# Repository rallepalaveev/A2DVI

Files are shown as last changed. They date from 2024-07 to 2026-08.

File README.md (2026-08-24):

# A2DVI - Apple II Digital Video

This is a project for a digital DVI/HDMI Apple II video card.
It directly produces a digital video stream from Apple II's memory content.
The signal is output via an HDMI connector, connecting the Apple II to modern displays with HDMI (or DVI) inputs.
No more analog signal conversion required.

The project is a collaboration with Thorsten Brehm. His related firmware project is here: https://github.com/ThorstenBr/A2DVI-Firmware

For the DVI output to be active, the new firmware developed by Thorsten should be used.

The card also has an alternative analog VGA connector.
For the VGA output to be active, the [VGA firmware](https://github.com/markadev/AppleII-VGA) developed by Mark Aikens should be used.

The card can produce either an analog VGA or a digital HDMI signal, but not both simultaneously.
To switch between modes, a firmware update is required and opening/closing connections.

As of v2.0 VGA function is not supported - the card is DVI only.

V2.2 has an onboard driver to invoke the configuation utility by PR#N, where N is the slot number.

V2.3 is a TH version with 74HC245 and requires a DVI break-out board.

V2.4 is a TH version with 74HC244 and requires a DVI break-out board.

## Procedure to activate DVI mode
* v1.2:
  program [A2DVI-Firmware](https://github.com/ThorstenBr/A2DVI-Firmware) to RPI Pico;
  remove U6 and disconnect pins 11, 12 and 13 of U5.
* v1.5:
  program [A2DVI-Firmware](https://github.com/ThorstenBr/A2DVI-Firmware) to RPI Pico;
  open all 9 DIP switches.
* v1.6:
  program [A2DVI-Firmware](https://github.com/ThorstenBr/A2DVI-Firmware) to RPI Pico;
  desloder the 8 soldering pads at GPIOs 14-21.
* v1.7:
  program [A2DVI-Firmware](https://github.com/ThorstenBr/A2DVI-Firmware) to RPI Pico;
  desloder the 8 soldering pads at GPIOs 14-21; remove VGA sub-board and ribbon cable.
* v2.0:
  program [A2DVI-Firmware](https://github.com/ThorstenBr/A2DVI-Firmware) to RPI Pico.
* v2.2:
  program [A2DVI-Firmware](https://github.com/ThorstenBr/A2DVI-Firmware) to RPI Pico.
* v2.3:
  program [A2DVI-Firmware](https://github.com/ThorstenBr/A2DVI-Firmware) to RPI Pico.
* v2.4:
  program [A2DVI-Firmware](https://github.com/ThorstenBr/A2DVI-Firmware) to RPI Pico.
  
## Procedure to activate VGA mode
* v1.2:
  program [VGA firmware](https://github.com/markadev/AppleII-VGA) to RPI Pico;
  replace U5 and U6.
* v1.5:
  program [VGA firmware](https://github.com/markadev/AppleII-VGA) to RPI Pico;
  close all 9 DIP switches.
* v1.6:
  program [VGA firmware](https://github.com/markadev/AppleII-VGA) to RPI Pico;
  sloder the 8 soldering pads at GPIOs 14-21.
* v1.7:
  program [VGA firmware](https://github.com/markadev/AppleII-VGA) to RPI Pico;
  sloder the 8 soldering pads at GPIOs 14-21; connect VGA sub-board to main board by the ribbon cable.
* v2.0:
  N.A. - v2.0 is HDMI only.
* v2.2:
  N.A. - v2.2 is HDMI only.
* v2.3:
  N.A. - v2.3 is HDMI only.
* v2.4:
  N.A. - v2.4 is HDMI only.
* v4.4:
  N.A. - v4.4 is HDMI only.
* v4.6:
  N.A. - v4.6 is HDMI only.
  * v5.x:
  N.A. - v5.x are HDMI only.

Note: In version 2.4 I experimented with replacing the 8x 270-ohms resistors on the DVI lines by 100pF capacitors to achieve better separation form potential 3.3V DC leak from the screen; while this worked, some screens are more prone to noise and results may still be better with the 270-ohms resistors.

Note2: Version 4.4 is bidirectional and can work as a variety of functionalities. Firmware is closed source so far. V4.6 has some optimizations.

Note3: Versions 5.x are based on CPB with RP2354B and are 5V tolerant and has 48 GPIOs available. This eliminates the need
for level shifting and multiplexing. This version had DVI function and can support RTC via a dedicated connector.

## Dual-Language Support
The pin on the v1.5 and later boards is for AltChr connection, supported by A2DVI firmware for switching between alternative character sets on non-US versions of Apple II ("Euro-machines").

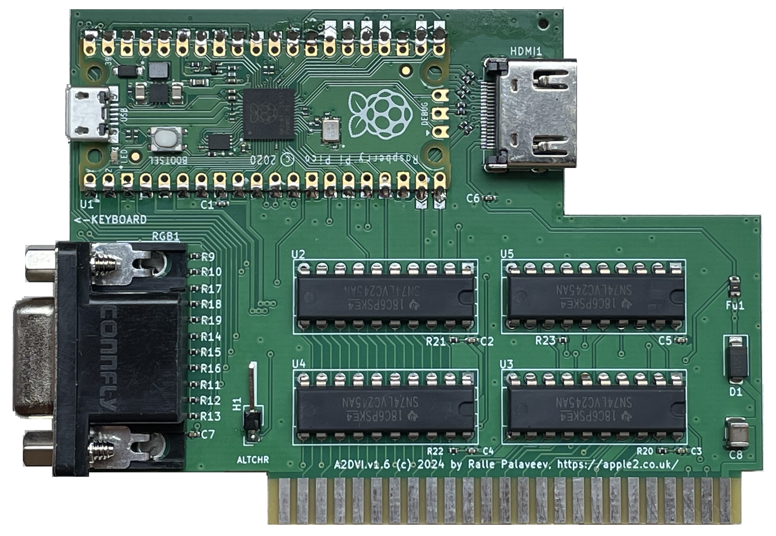
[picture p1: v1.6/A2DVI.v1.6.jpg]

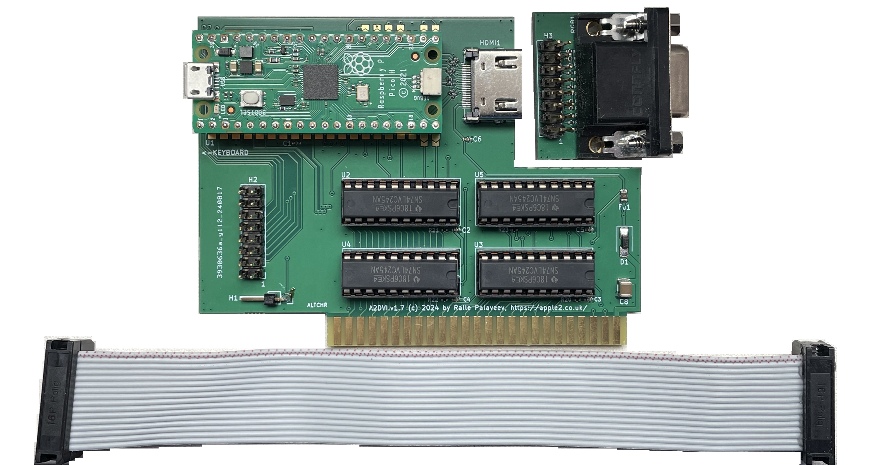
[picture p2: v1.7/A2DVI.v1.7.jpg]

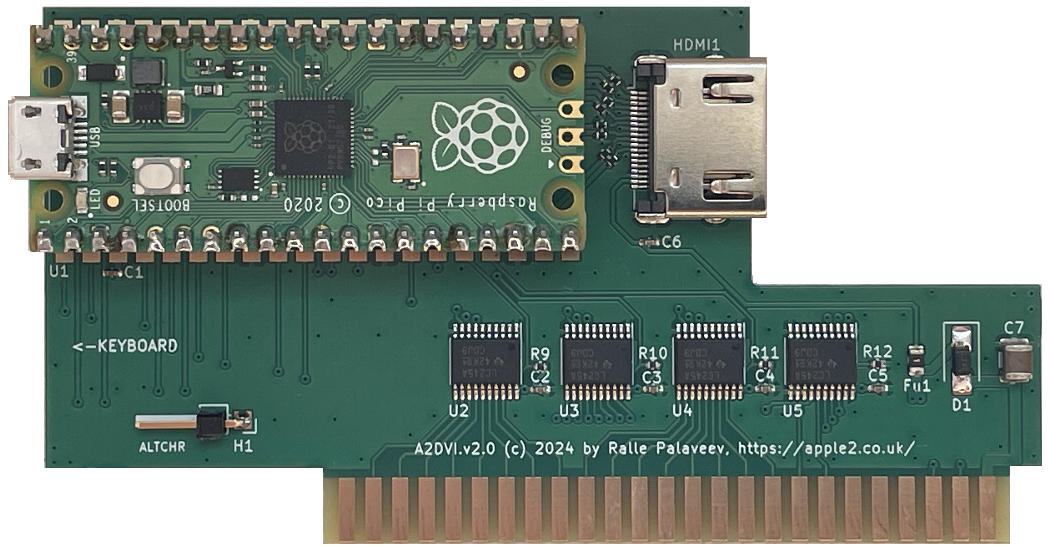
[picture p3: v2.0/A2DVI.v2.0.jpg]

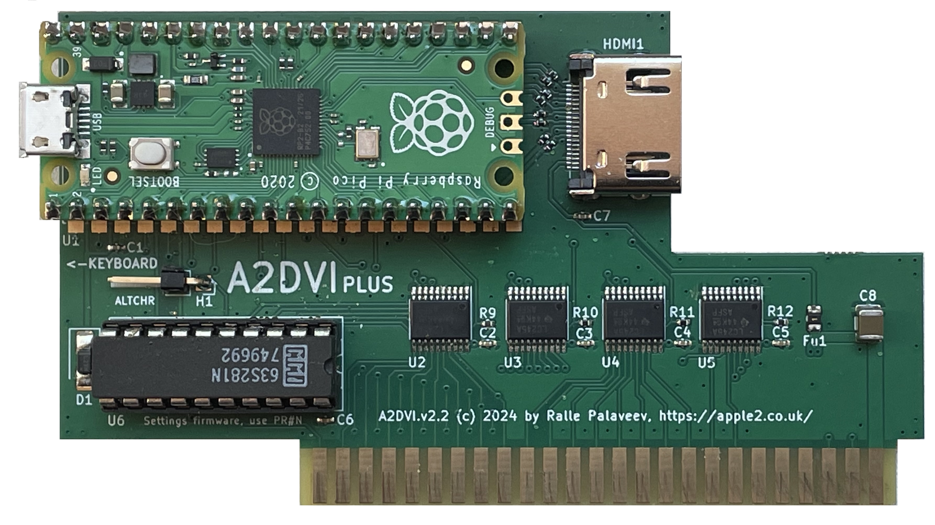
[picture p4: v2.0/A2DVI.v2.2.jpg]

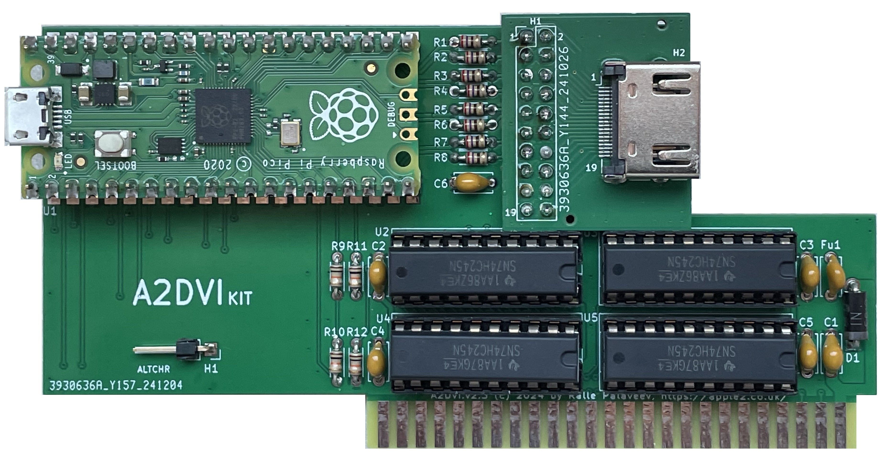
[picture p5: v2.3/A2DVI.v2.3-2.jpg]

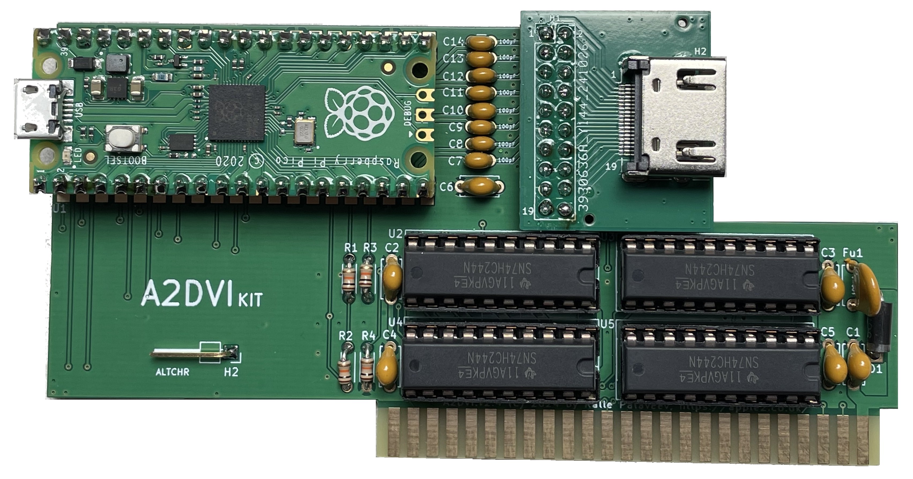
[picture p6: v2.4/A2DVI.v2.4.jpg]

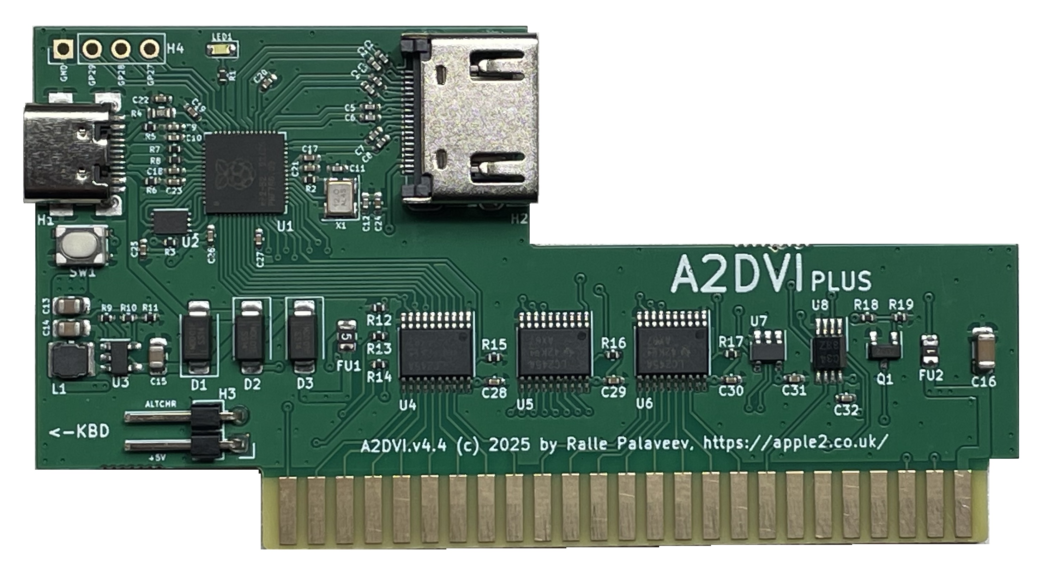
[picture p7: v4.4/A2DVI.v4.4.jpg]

A2DVI PCB
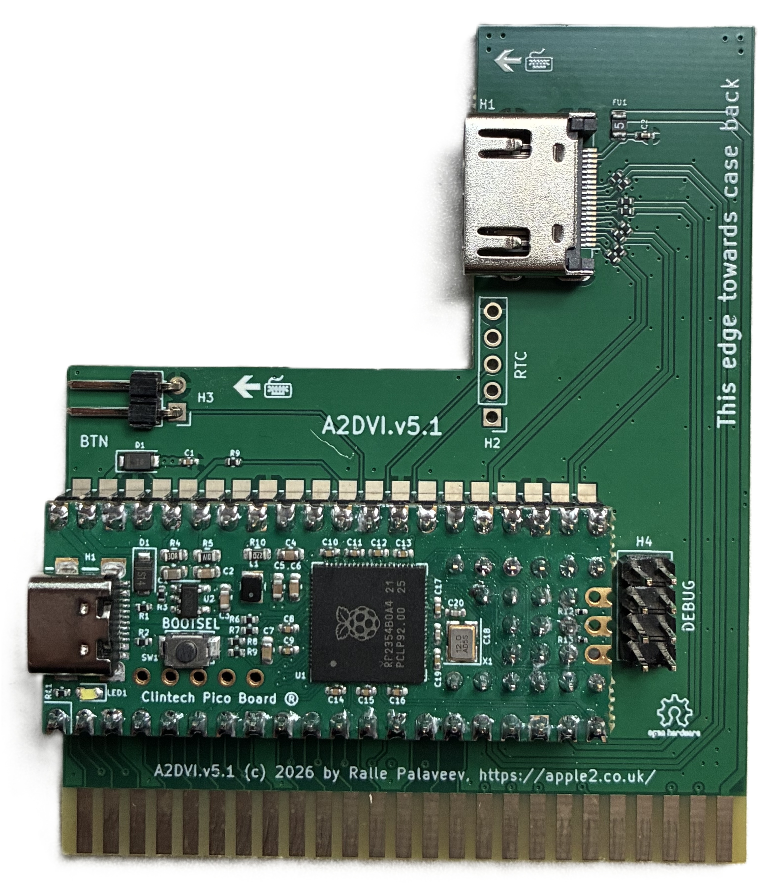
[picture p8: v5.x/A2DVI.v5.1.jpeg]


# Hardware
* Based on the PICO controller board.
* Provides a DVI video stream via an HDMI connector.
* Low power/heat dissipation: less than 70mA@5V = 0.35W in operation.
* Uses 4x 74LV245 bus transceivers for 5V/3.3V signal conversion of the Apple II bus.
* Separate ALTCHR input pin for dual-language support: pin needs to be wired separately to the "language switch" of Euro-Apple IIs (optional).
* Versions 5.x do not need level shifters.

# Thanks
This is a project based on:

* the AppleII-VGA project by Mark Aikens - https://github.com/markadev/AppleII-VGA

* the PicoDVI project by Luke Wren - https://github.com/Wren6991/PicoDVI

* Thorsten Brehm for firmware development and board design considerations

* Oliver Schmidt on original idea discussions and design considerations

* Mike Neil for adapting the firmware for v5.x.

# License
Board design by Ralle Palaveev (c) 2026.

All rights reserved.

Redistribution and use in source, binary, and manufactured forms, with or without
modification, are permitted provided that the following conditions are met:
1. Redistributions of source code and design files must retain the above copyright
   notice, this list of conditions and the following disclaimer.
2. Redistributions in binary or manufactured form must reproduce the above copyright
   notice, this list of conditions and the following disclaimer in the
   documentation and/or other materials provided with the distribution.
3. All advertising materials mentioning features or use of this software
   or hardware must display the following acknowledgement:
   This product includes software or hardware developed by Ralle Palaveev.
4. Neither the name of Ralle Palaveev nor the
   names of its contributors may be used to endorse or promote products
   derived from this software or hardware without specific prior written permission.

The above copyright notice and this permission notice shall be included in all
copies or substantial portions of the Software.

THE SOFTWARE IS PROVIDED "AS IS", WITHOUT WARRANTY OF ANY KIND, EXPRESS OR
IMPLIED, INCLUDING BUT NOT LIMITED TO THE WARRANTIES OF MERCHANTABILITY,
FITNESS FOR A PARTICULAR PURPOSE AND NONINFRINGEMENT. IN NO EVENT SHALL THE
AUTHORS OR COPYRIGHT HOLDERS BE LIABLE FOR ANY CLAIM, DAMAGES OR OTHER
LIABILITY, WHETHER IN AN ACTION OF CONTRACT, TORT OR OTHERWISE, ARISING FROM,
OUT OF OR IN CONNECTION WITH THE SOFTWARE OR THE USE OR OTHER DEALINGS IN THE
SOFTWARE.

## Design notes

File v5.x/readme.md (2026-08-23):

This is based on Clintech Pico Board (CPB) with 48 GPIOs, most 5V tolerant.

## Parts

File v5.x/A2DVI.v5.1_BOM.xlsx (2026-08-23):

Comment | Designator | Footprint | JLCPCB Part #（optional）
16V 100nF X7R ±10% 0402 Multilayer Ceramic Capacitors MLCC - SMD/SMT ROHS | C1,C2 | 0402 | C1525
DSS14 | D1 | SOD-123FL | C2923923
6V 500mA Resettable Fuse | FU1 | 0805-50 | C269104
HDMI connector | H1 |  | C2906135
270 | R1,R2,R3,R4,R5,R6,R7,R8 | 0402 | C324790
1k | R9 | 0402 | C11702

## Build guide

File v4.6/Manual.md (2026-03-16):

# A2DVI.v4.6: Digital Video card for Apple II Computers with multifunction capabilities

## Preface

This is a firmware project for a digital DVI/HDMI video card for Apple II. It directly produces a digital video stream from the Apple II's memory content. The signal is output via an HDMI connector, connecting the Apple II to modern displays with HDMI (or DVI) inputs. No analog signal conversion is required.

The project is a collaboration between Ralle Palaveev and Thorsten Brehm. 

The hardware is based on the PICO controller board. Both, original PICO (RP2040) and PICO2 (RP2350) modules are supported. Separate firmware is provided for the two PICO variants.

The initial designs v1.x and v2.x have been unidirectional where the card is snooping on the A2 computer address, data and control buses and creates a shadow image of what is to be displayed. The image is then sent to the HDMI output as digital video. More information on the technology is here: https://github.com/ThorstenBr/A2DVI-Firmware

Version 4.x of the card is now bi-directional and the hardware is directly manufactured with a RP2040 processor on board, instead a RPI Pico.

This new design allows for housing of programs on the card which can communicate back and forth with the A2 computer. This has allowed for several firmwares to be pre-loaded on the card and each one can be used at a time, turning the card into a specific function card.

## Firmwares on the card

Currently there are 5 firmwares on the card:

1. A2DVI - HDMI video display adapter
2. Z80 emulator for Applicard CPM
3. Apple II Mouse (PAL) - an adapter for a USB mouse for Apple2 for PAL video timing
4. Apple II Mouse (NTSC) - an adapter for a USB mouse for Apple2 for NTSC video timing
5. USB Floppy Disk II

Only one firmware is active at a time. A firmware can be selected by an initial selection menu, which can be invoked within 15 seconds of powering the computer by calling PR#N command, where N is the slot number.

Once the computer is powered, DVI is always active during the 15s timeout, so that the user can see the menu for firmware selection. If the DVI firmware is not the one selected, the bottom of the screen displays which firmware would become active and the timeout counter. During the initial 15s timeout the LED blinks very fast.

Once a firmware is selected, the timeout ends immediately and the selected firmware becomes active.

Alternatively, if during the 15 second timeout nothing is done, upon timeout completion the previously selected firmware becomes active.

If cold reset is performed (Ctrl-OpenApple-Reset), this does not affect the function of the firmware - the timeout is not invoked. It is only active after a power on.

## Each firmware function is described below.

1. A2DVI. All functions are the same as described in the original design of version 2.x: https://github.com/ThorstenBr/A2DVI-Firmware The only difference is that by running PR#N, while DVI is active, the DVI configuration menu would be started - no config disk is needed. During DVI function the LED blinks fast.

2. Z80 emulator for Applicard CPM. If this mode is selected, then the user can boot Applicard CPM, an example disk is here: https://github.com/rallepalaveev/A2DVI/blob/main/v4.4/PCPI%20AppliCard%20D1.po Suggested card slot: 4.

3. Apple II Mouse Card (PAL). This firmware turns the card into a Mouse controller - it has to be installed in Slot4 and a USB mouse connected to the USB-c port of the card (an adapter may be needed for USB-A mouse). Once the firmware becomes active (15s after power-on), the card can be used by programs like A2Desktop.

4. Apple II Mouse Card (NTSC). This firmware turns the card into a Mouse controller - it has to be installed in Slot4 and a USB mouse connected to the USB-c port of the card (an adapter may be needed for USB-A mouse). Once the firmware becomes active (15s after power-on), the card can be used by programs like A2Desktop.

5. When FDD is selected and activated, the LED blinks slowly until the 2 floppy disk images are selected; calling PR#N displays a menu to select disk images for the 2 floppy disk drives. The 140kB .dsk images must be on a thumb drive connected to the USB-c port of the card. After selecting the disk images, the LED blinks synchronously with the floppy disk access. Currently works on IIe only. If programs require to change disks: The current solution is to connect an external button (A2DVIplus has a two pin connector to connect a button/switch). The firmware detects floppy images with names only differing in a single digit. So, the trick is to prepare the disk images to follow a naming scheme. "Oregon Trail - Disk1.dsk", "Oregon Trail - Disk 2.dsk" etc. Then you just select the boot disk via the menu. And when the program later asks to flip/cycle disks, you simply press the button to advance one digit ahead. The firmware automatically cycles through the disk images - in ascending order. Just sometimes requires a bit of preparation. Something like "Prince of Persia (boot disk).dsk", "Prince of Persia (side a).dsk" doesn't work, so some images need to be renamed.

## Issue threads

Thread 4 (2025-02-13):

No A2DVI Card in Slot X #20

amazingcobrazil, 2025-02-13:
Hello,
I assembled a board for my own use, and it is displaying the image normally, but when I run the configuration utility files, it displays the error message:
No A2DVI Card in Slot 1
I have already tried changing it to other slots on my Apple IIe and the message is the same. I tried both the A2DVICONFIG_DOS33.dsk and A2DVICONFIG_DOS33.po images (downloaded from the same package as the latest firmware 1.7)
My board version: 2.0
What could it be?

rallepalaveev, 2025-02-13:
Hi,

Where is this message displaying? On the standard Apple2 output or on the HDMI? Please note that while the CONFIG is running, the outputs are showing different screens.

Let me know if that helps.

Closed 2025-03-11.

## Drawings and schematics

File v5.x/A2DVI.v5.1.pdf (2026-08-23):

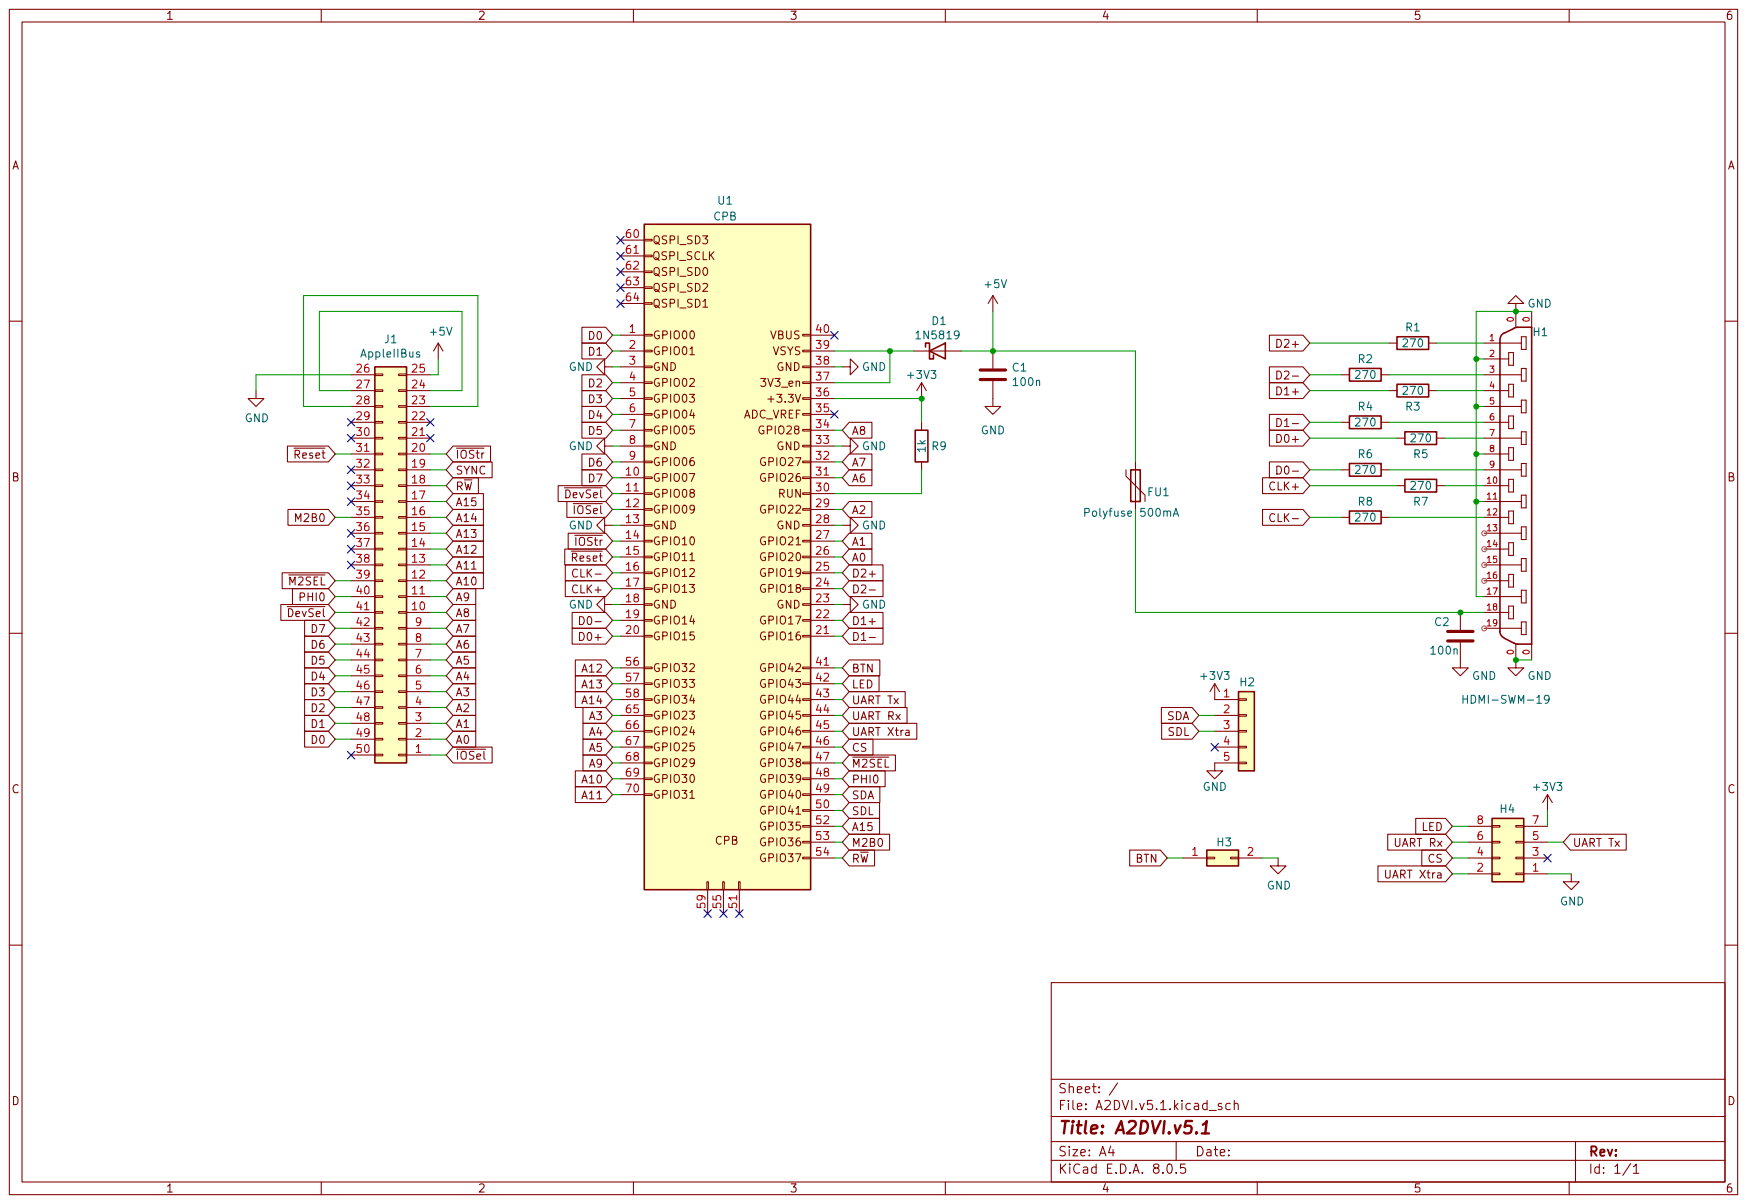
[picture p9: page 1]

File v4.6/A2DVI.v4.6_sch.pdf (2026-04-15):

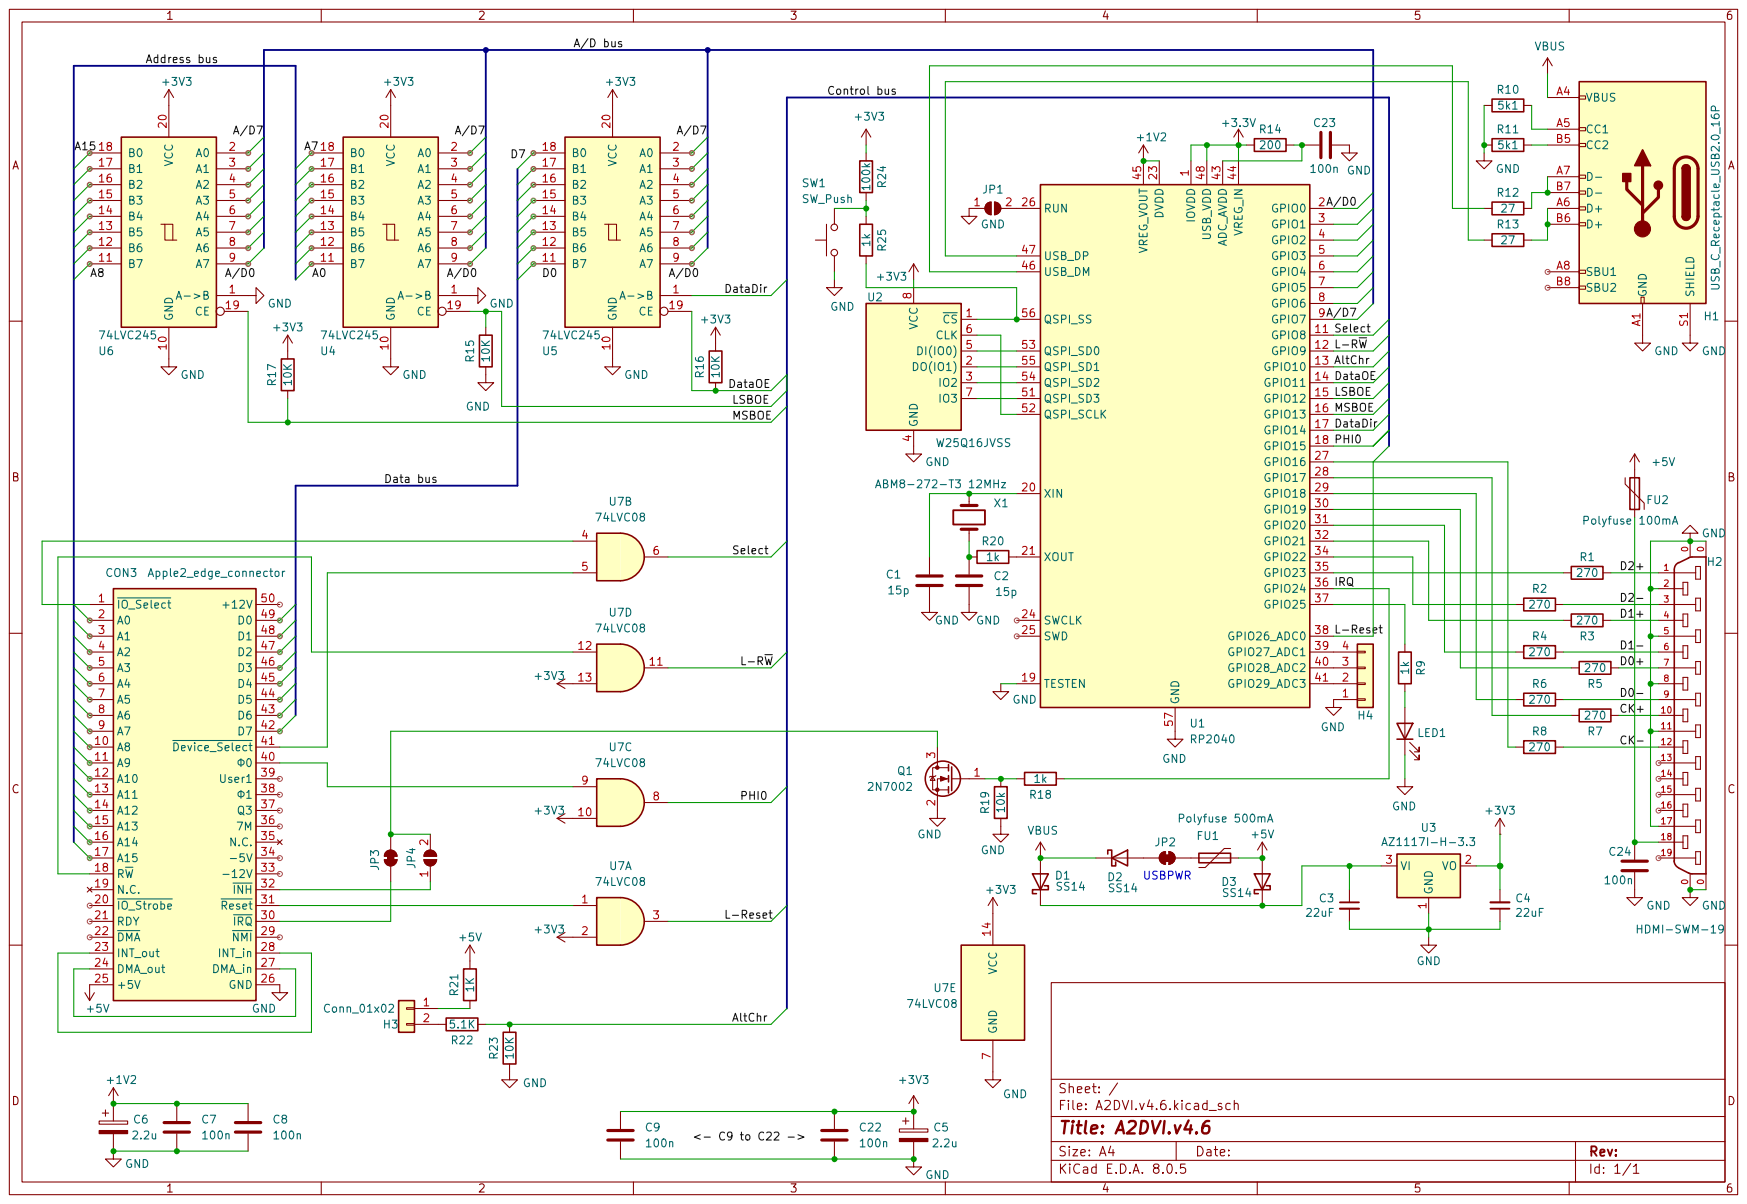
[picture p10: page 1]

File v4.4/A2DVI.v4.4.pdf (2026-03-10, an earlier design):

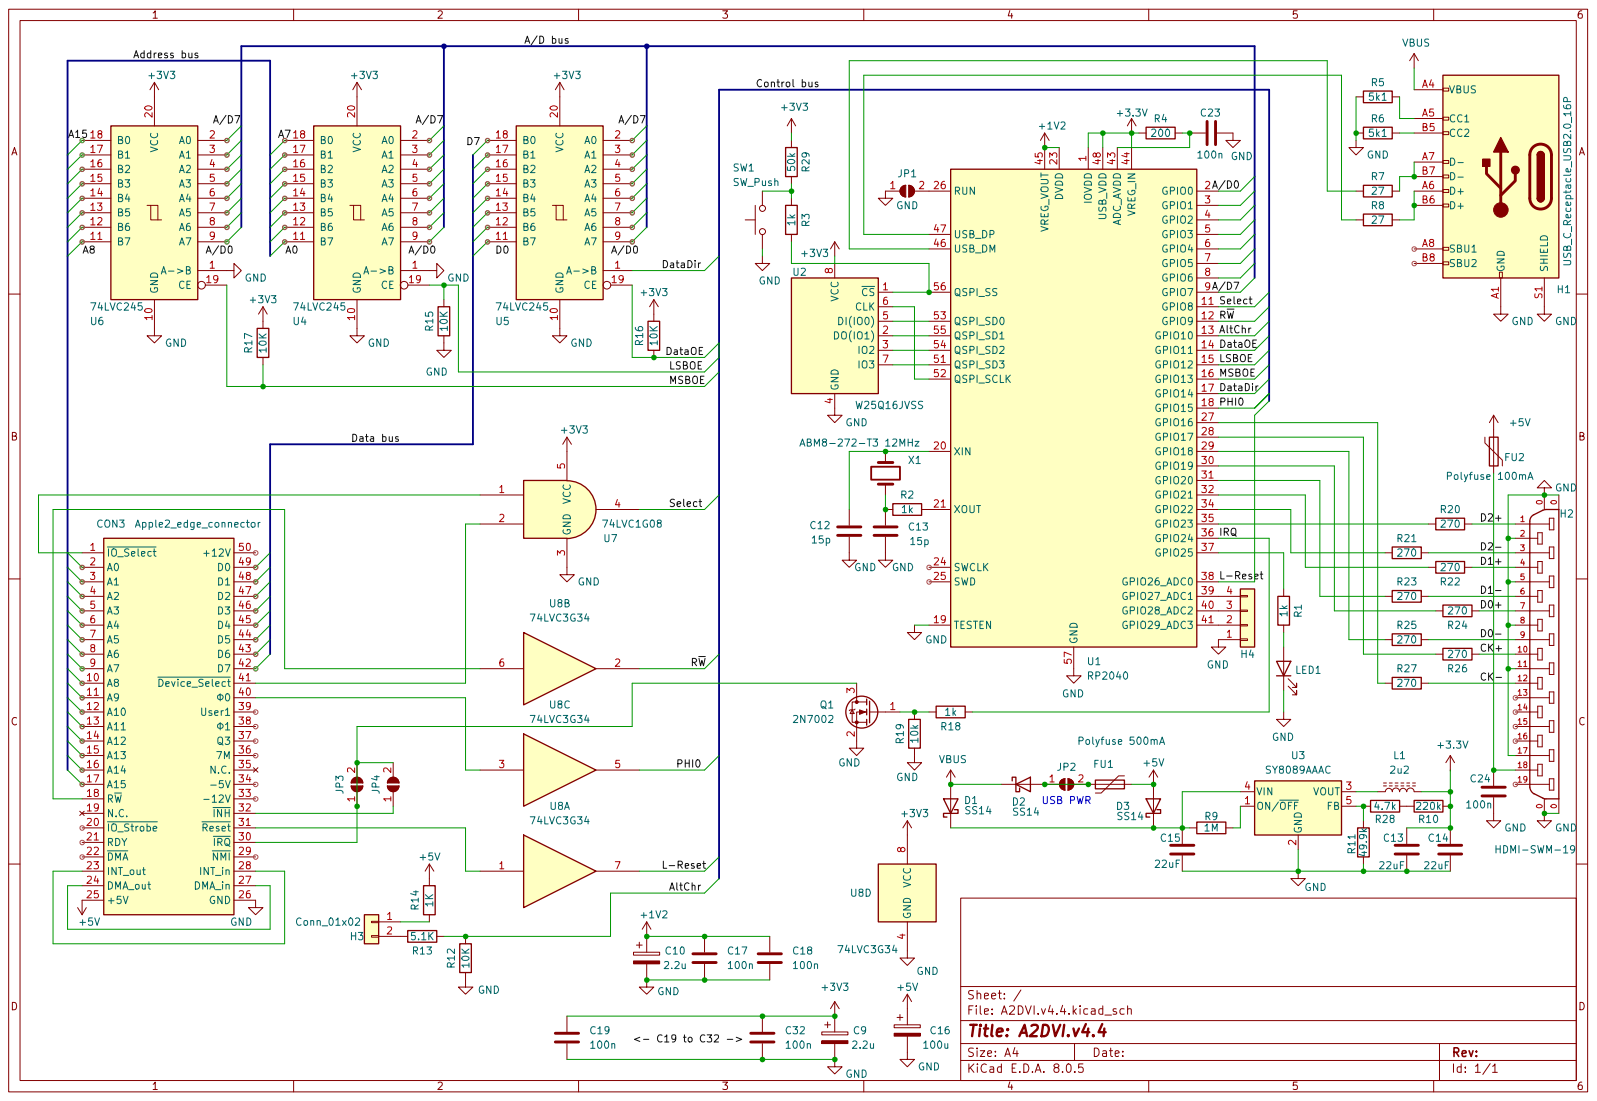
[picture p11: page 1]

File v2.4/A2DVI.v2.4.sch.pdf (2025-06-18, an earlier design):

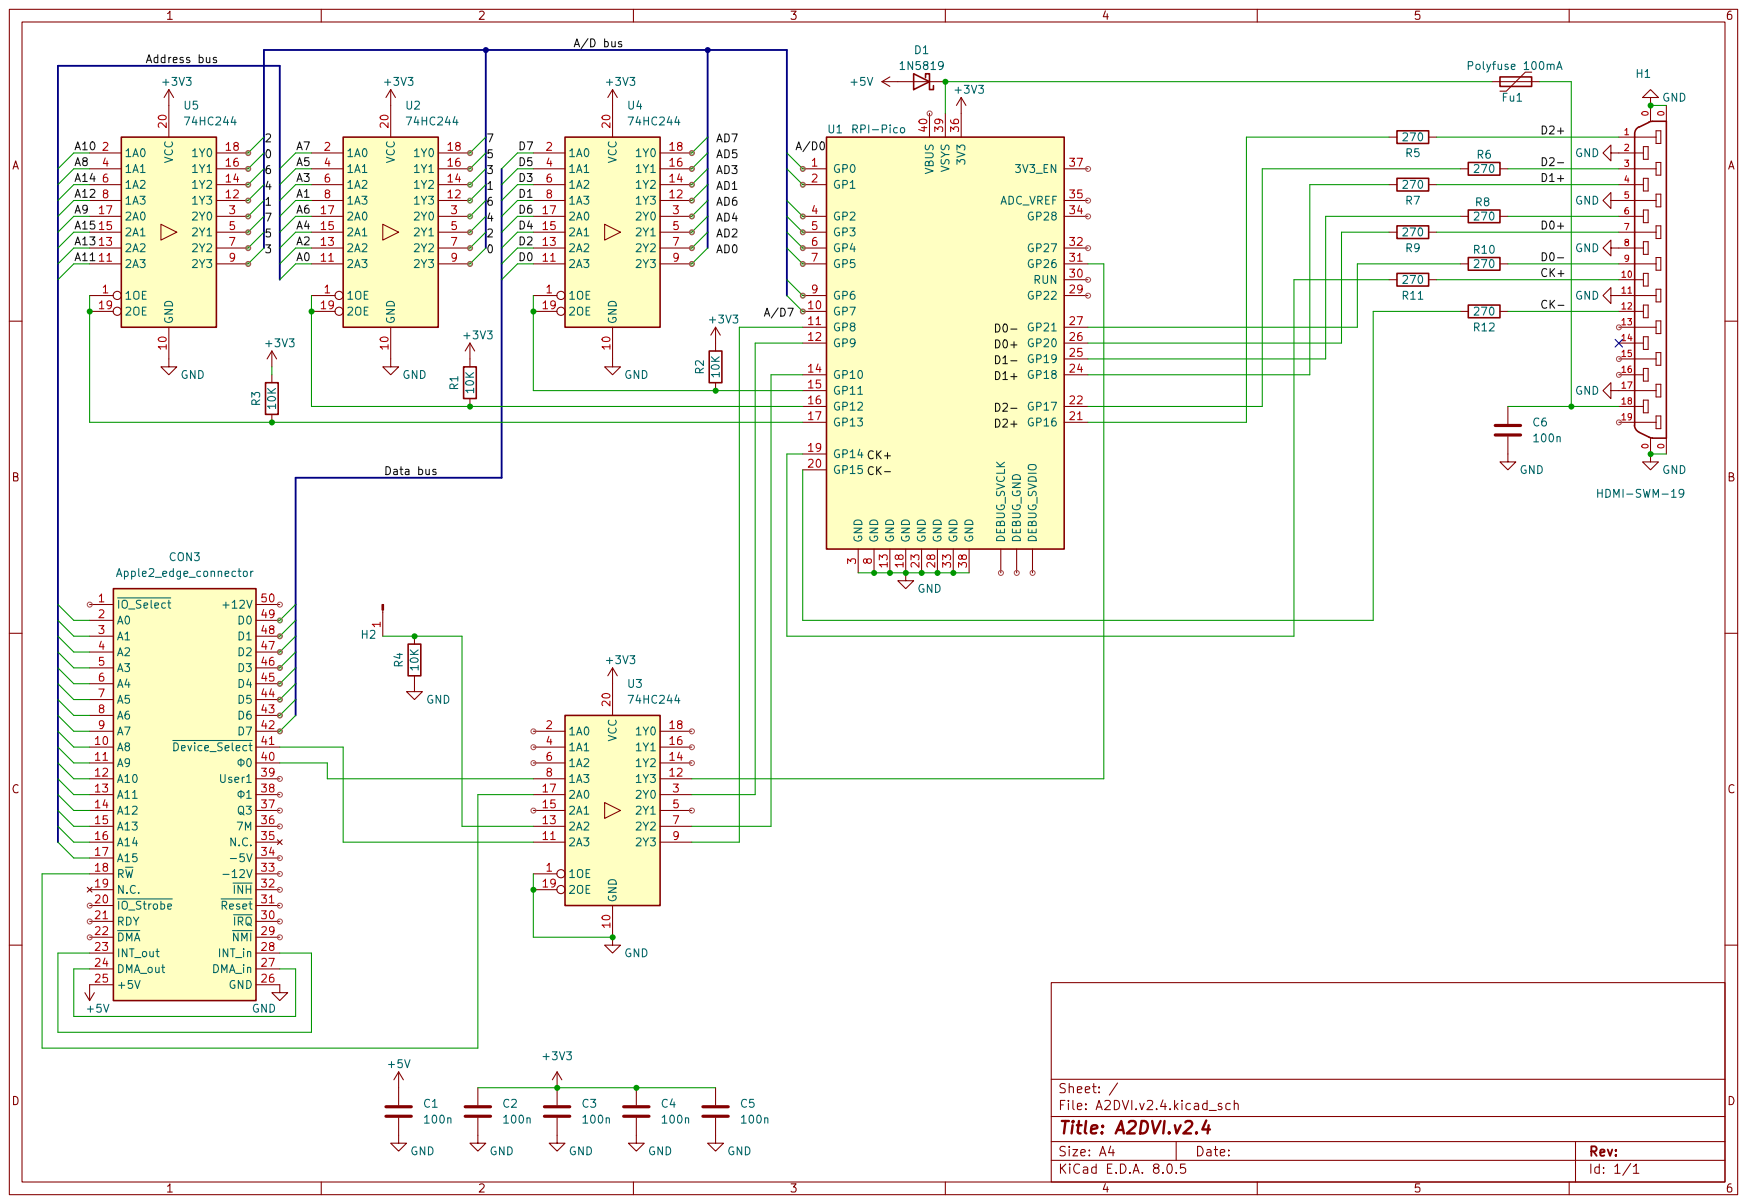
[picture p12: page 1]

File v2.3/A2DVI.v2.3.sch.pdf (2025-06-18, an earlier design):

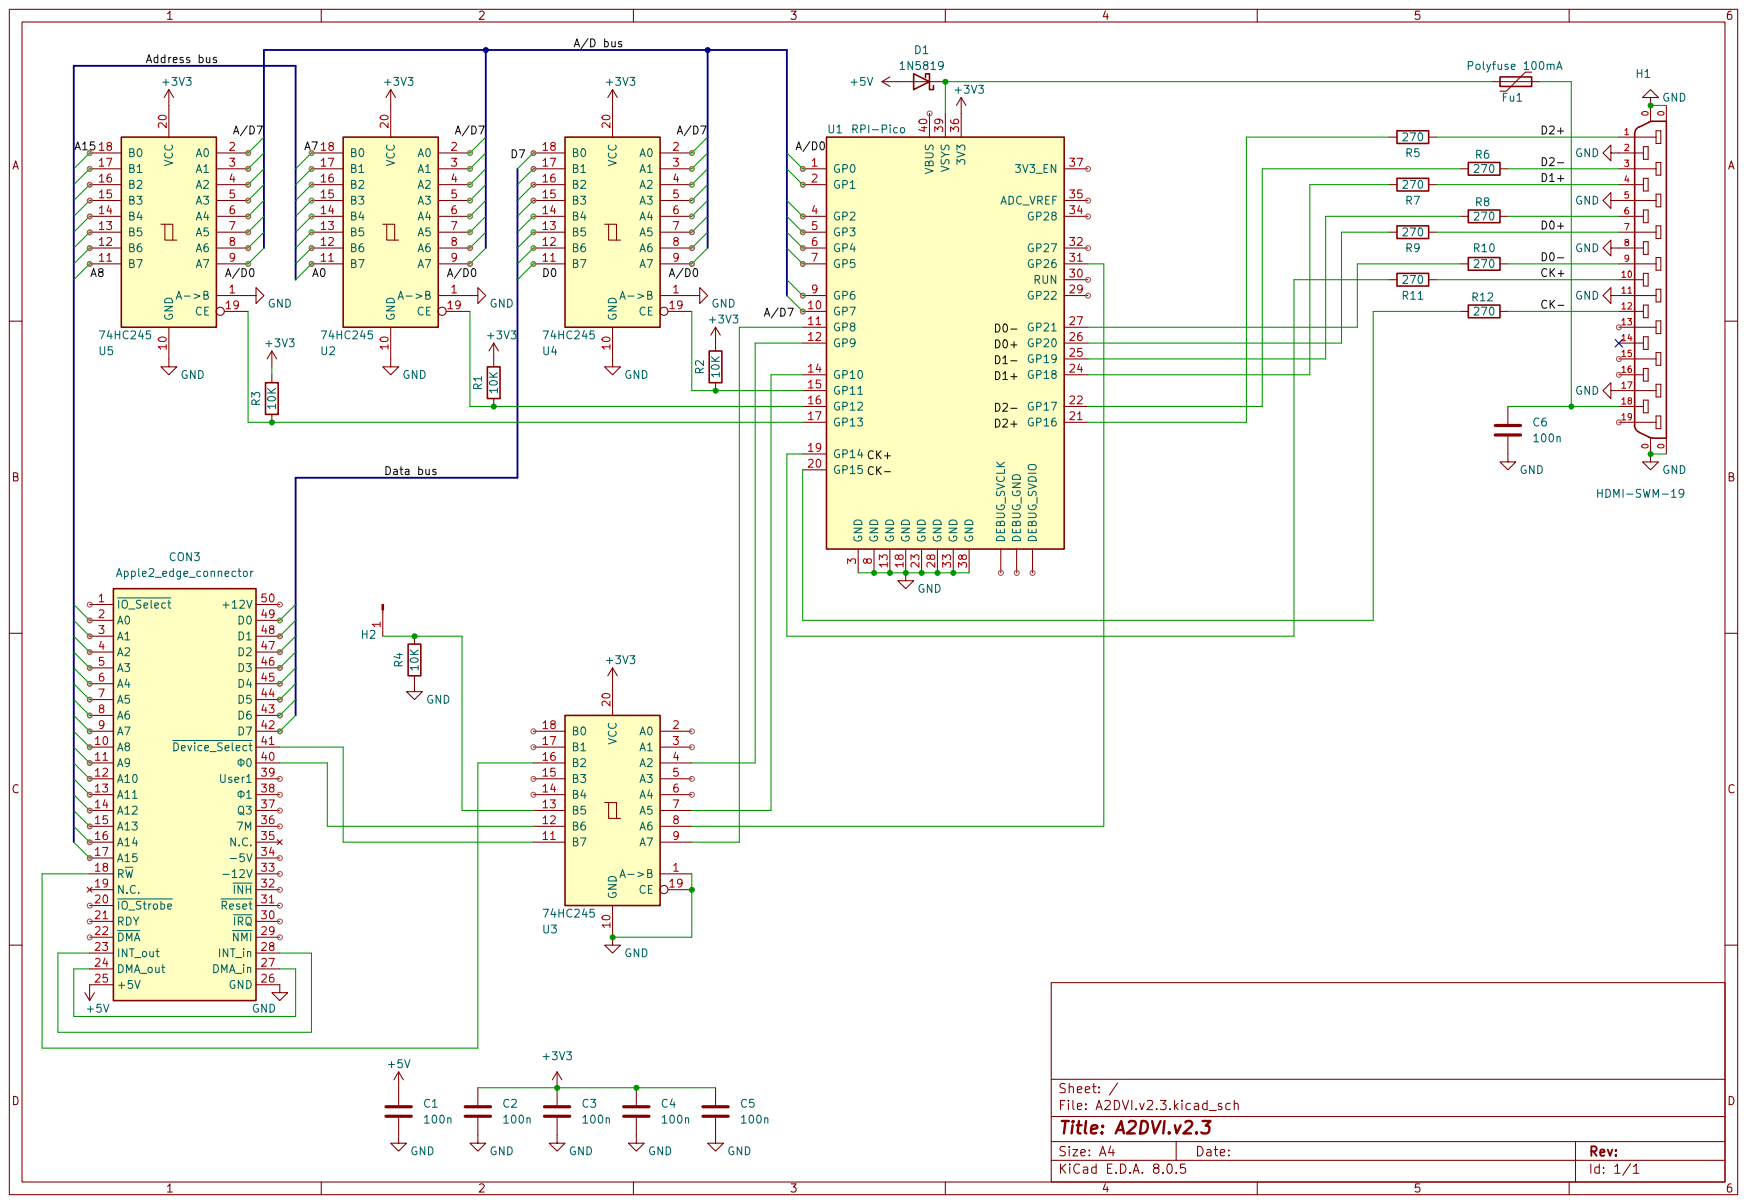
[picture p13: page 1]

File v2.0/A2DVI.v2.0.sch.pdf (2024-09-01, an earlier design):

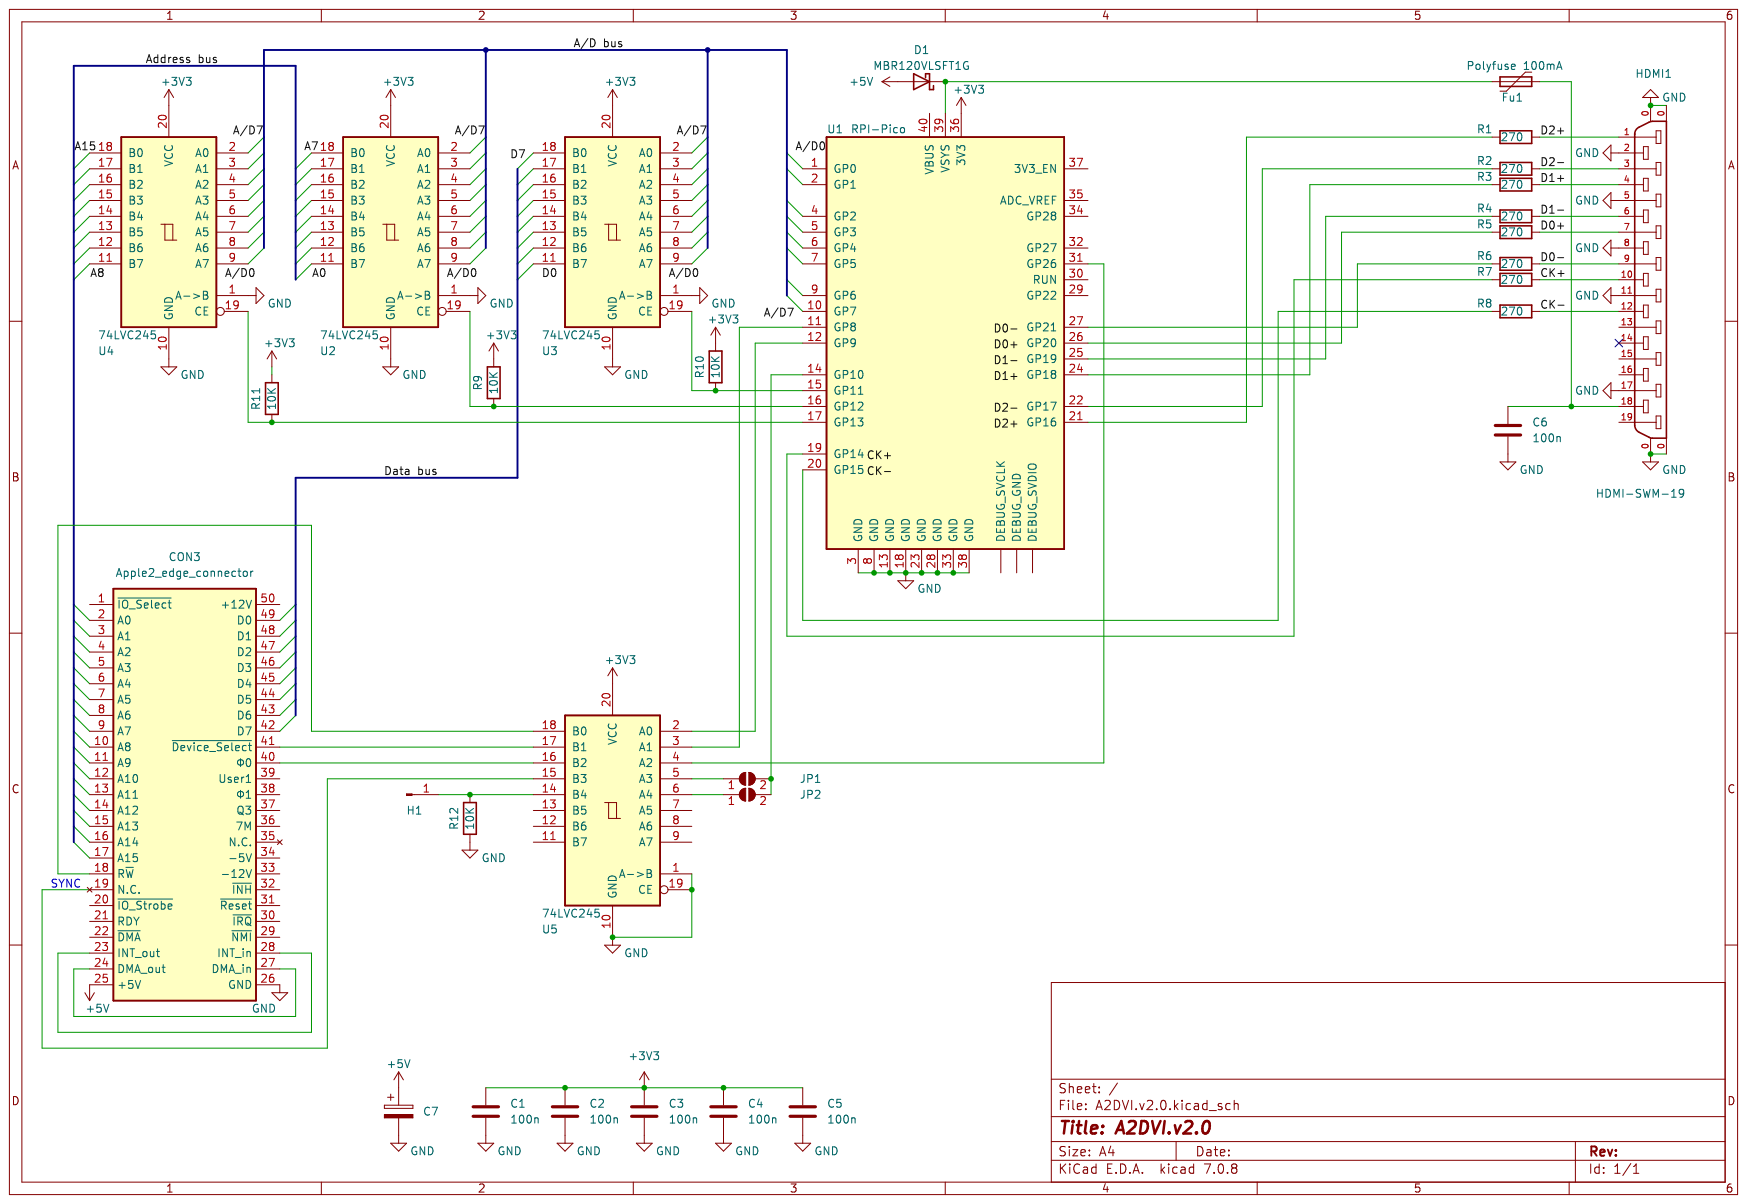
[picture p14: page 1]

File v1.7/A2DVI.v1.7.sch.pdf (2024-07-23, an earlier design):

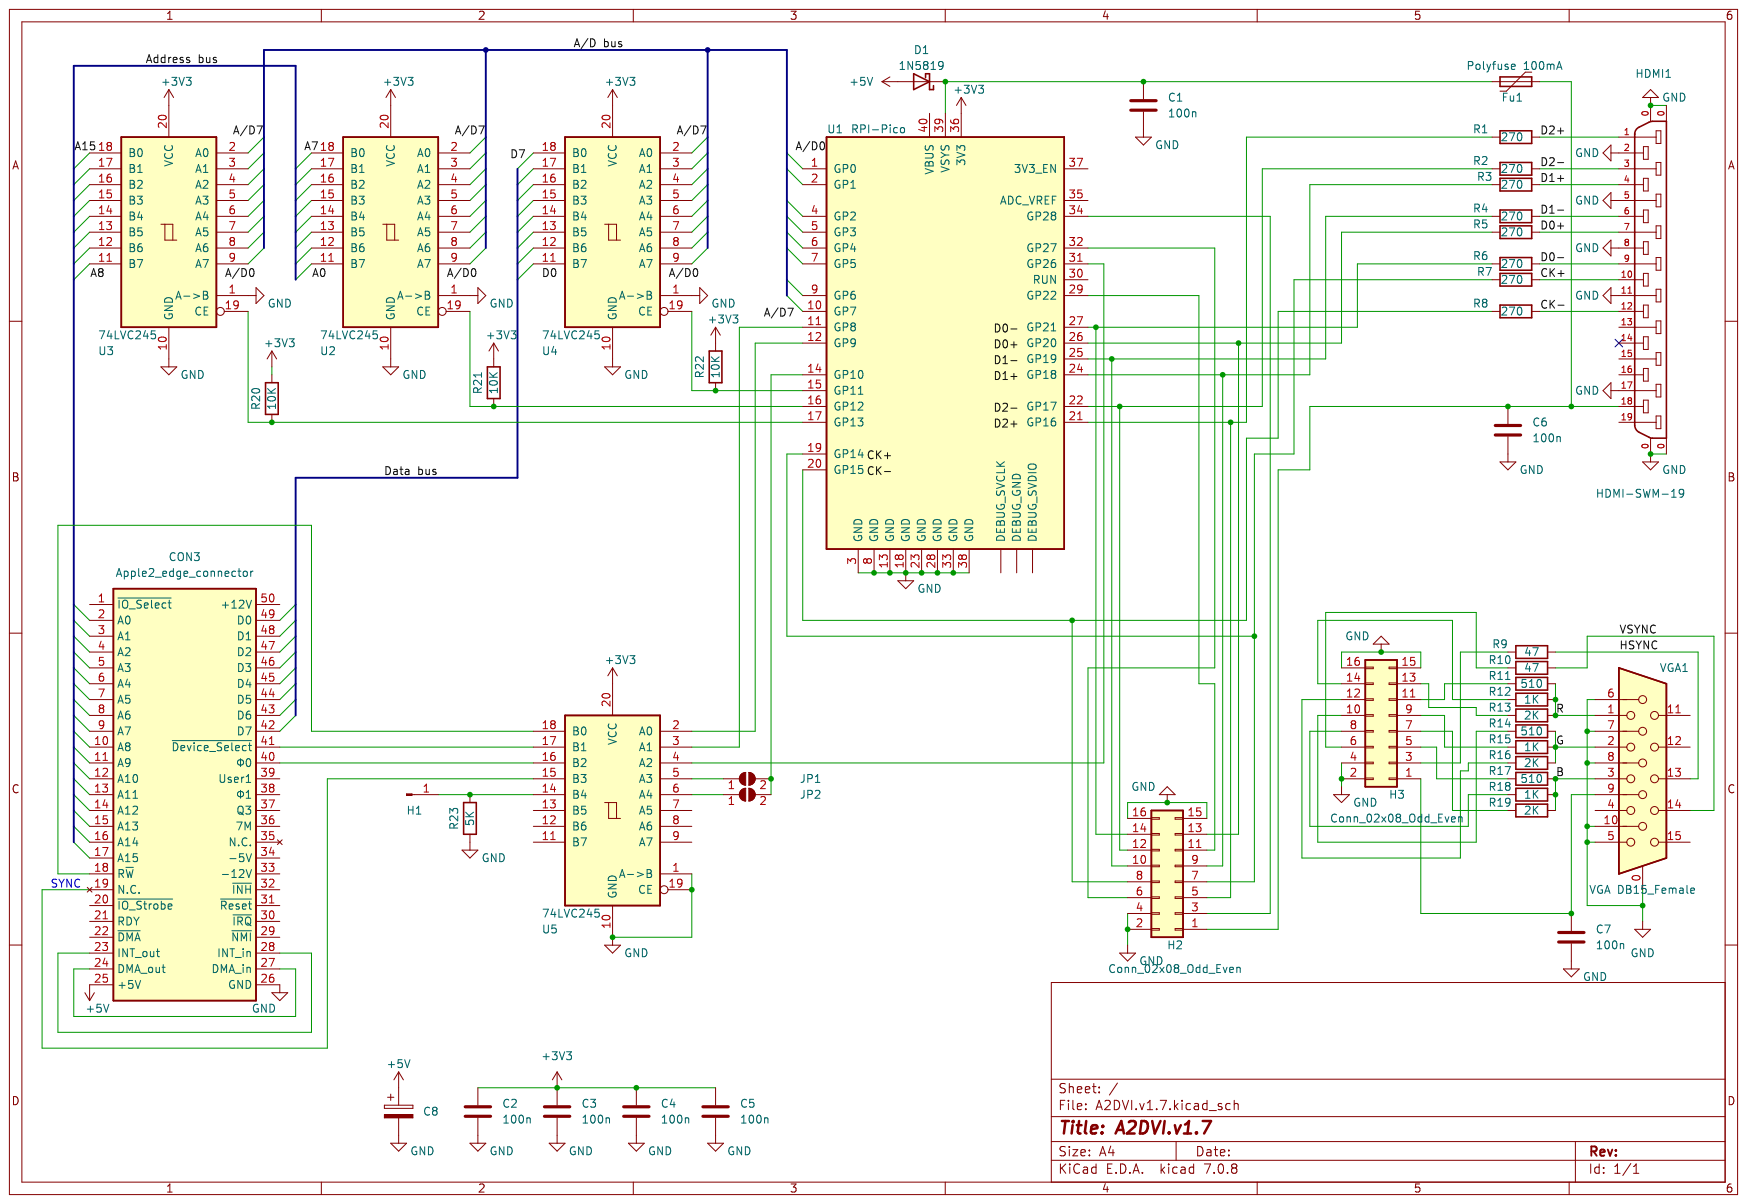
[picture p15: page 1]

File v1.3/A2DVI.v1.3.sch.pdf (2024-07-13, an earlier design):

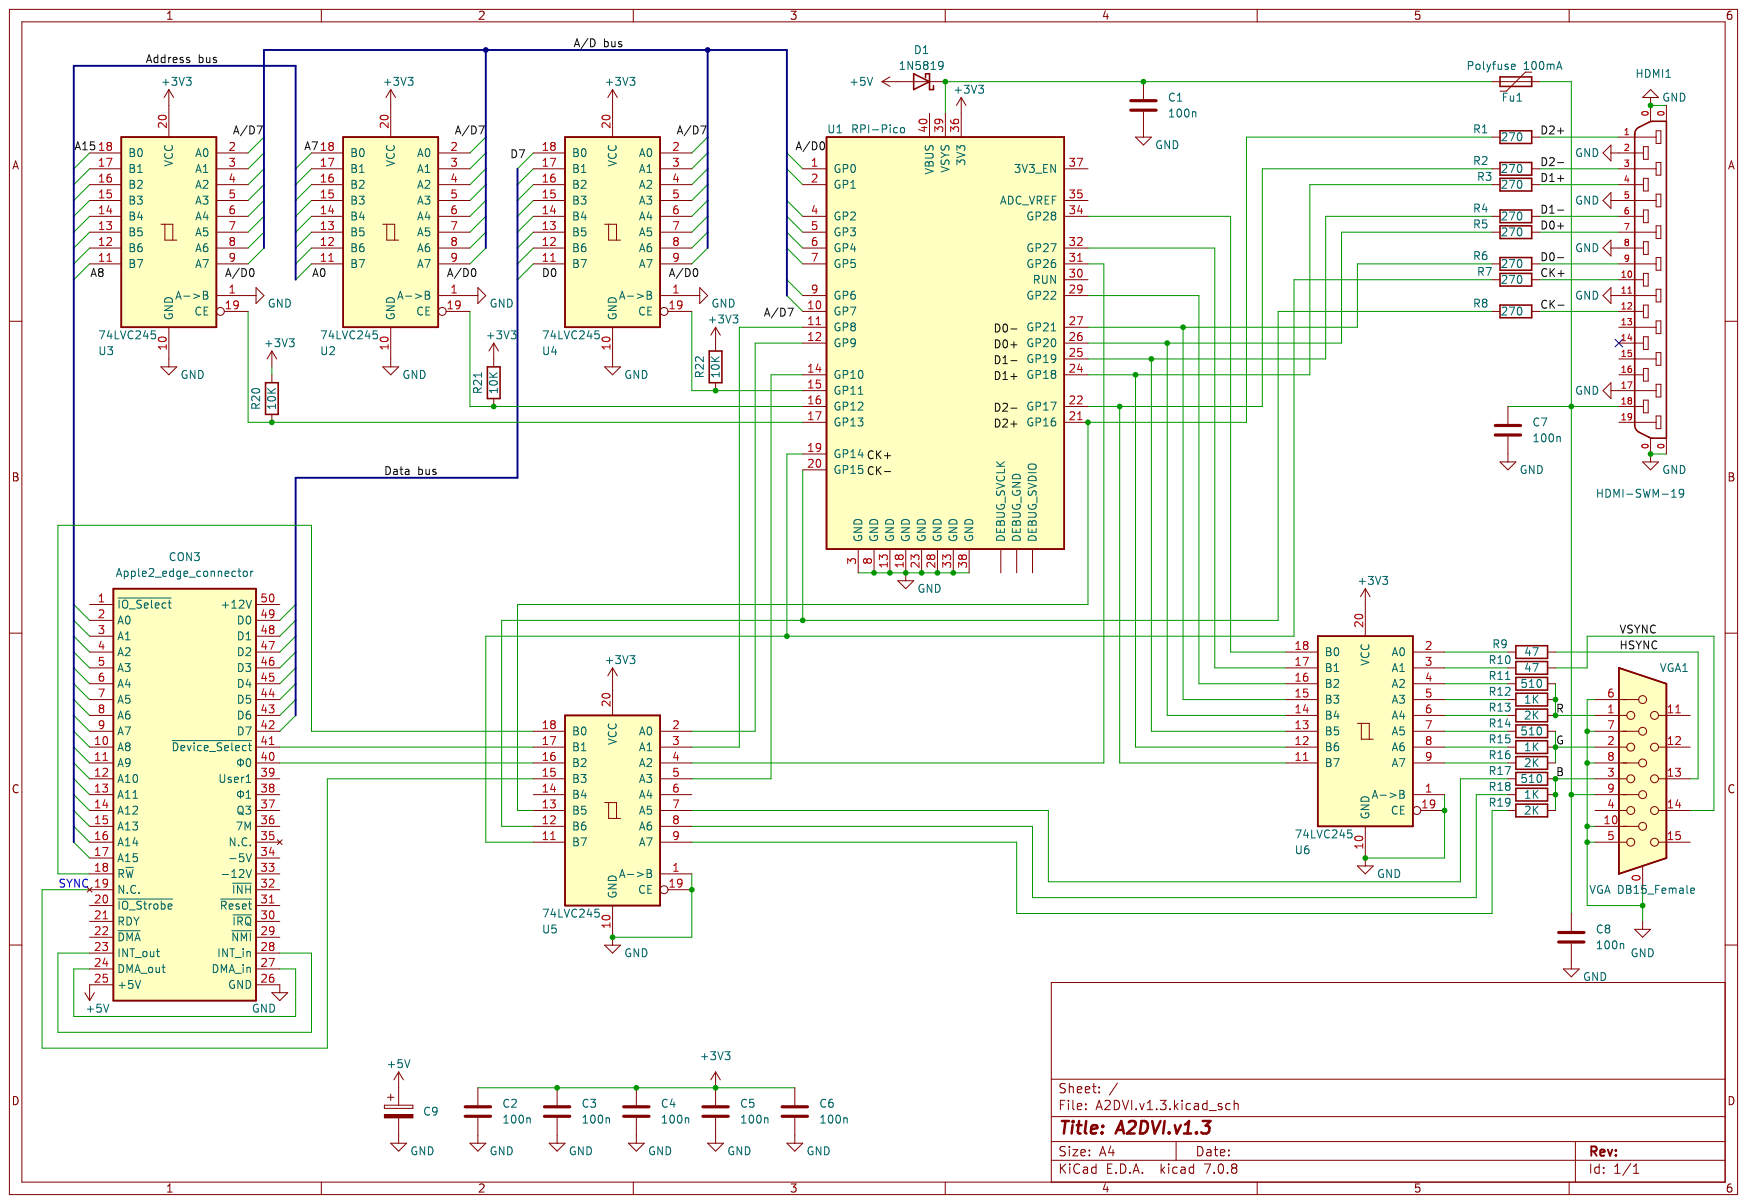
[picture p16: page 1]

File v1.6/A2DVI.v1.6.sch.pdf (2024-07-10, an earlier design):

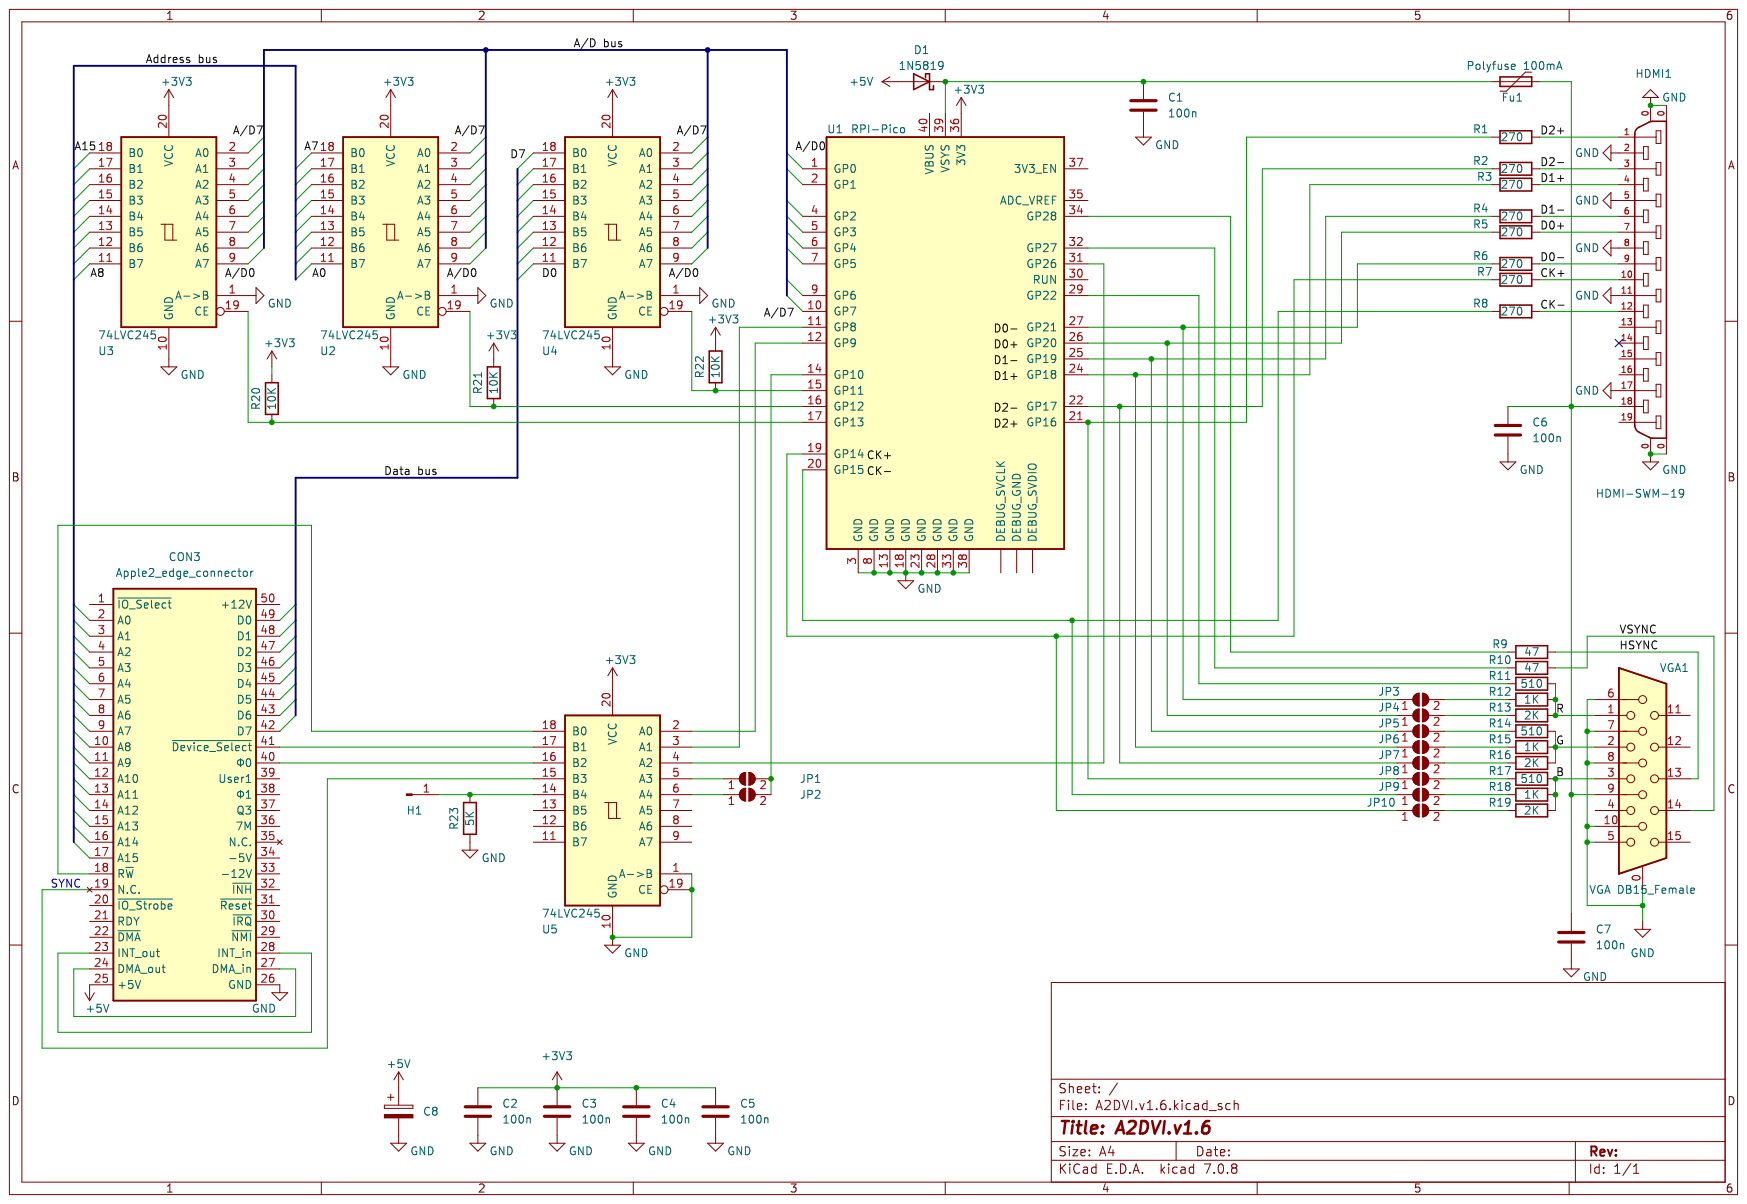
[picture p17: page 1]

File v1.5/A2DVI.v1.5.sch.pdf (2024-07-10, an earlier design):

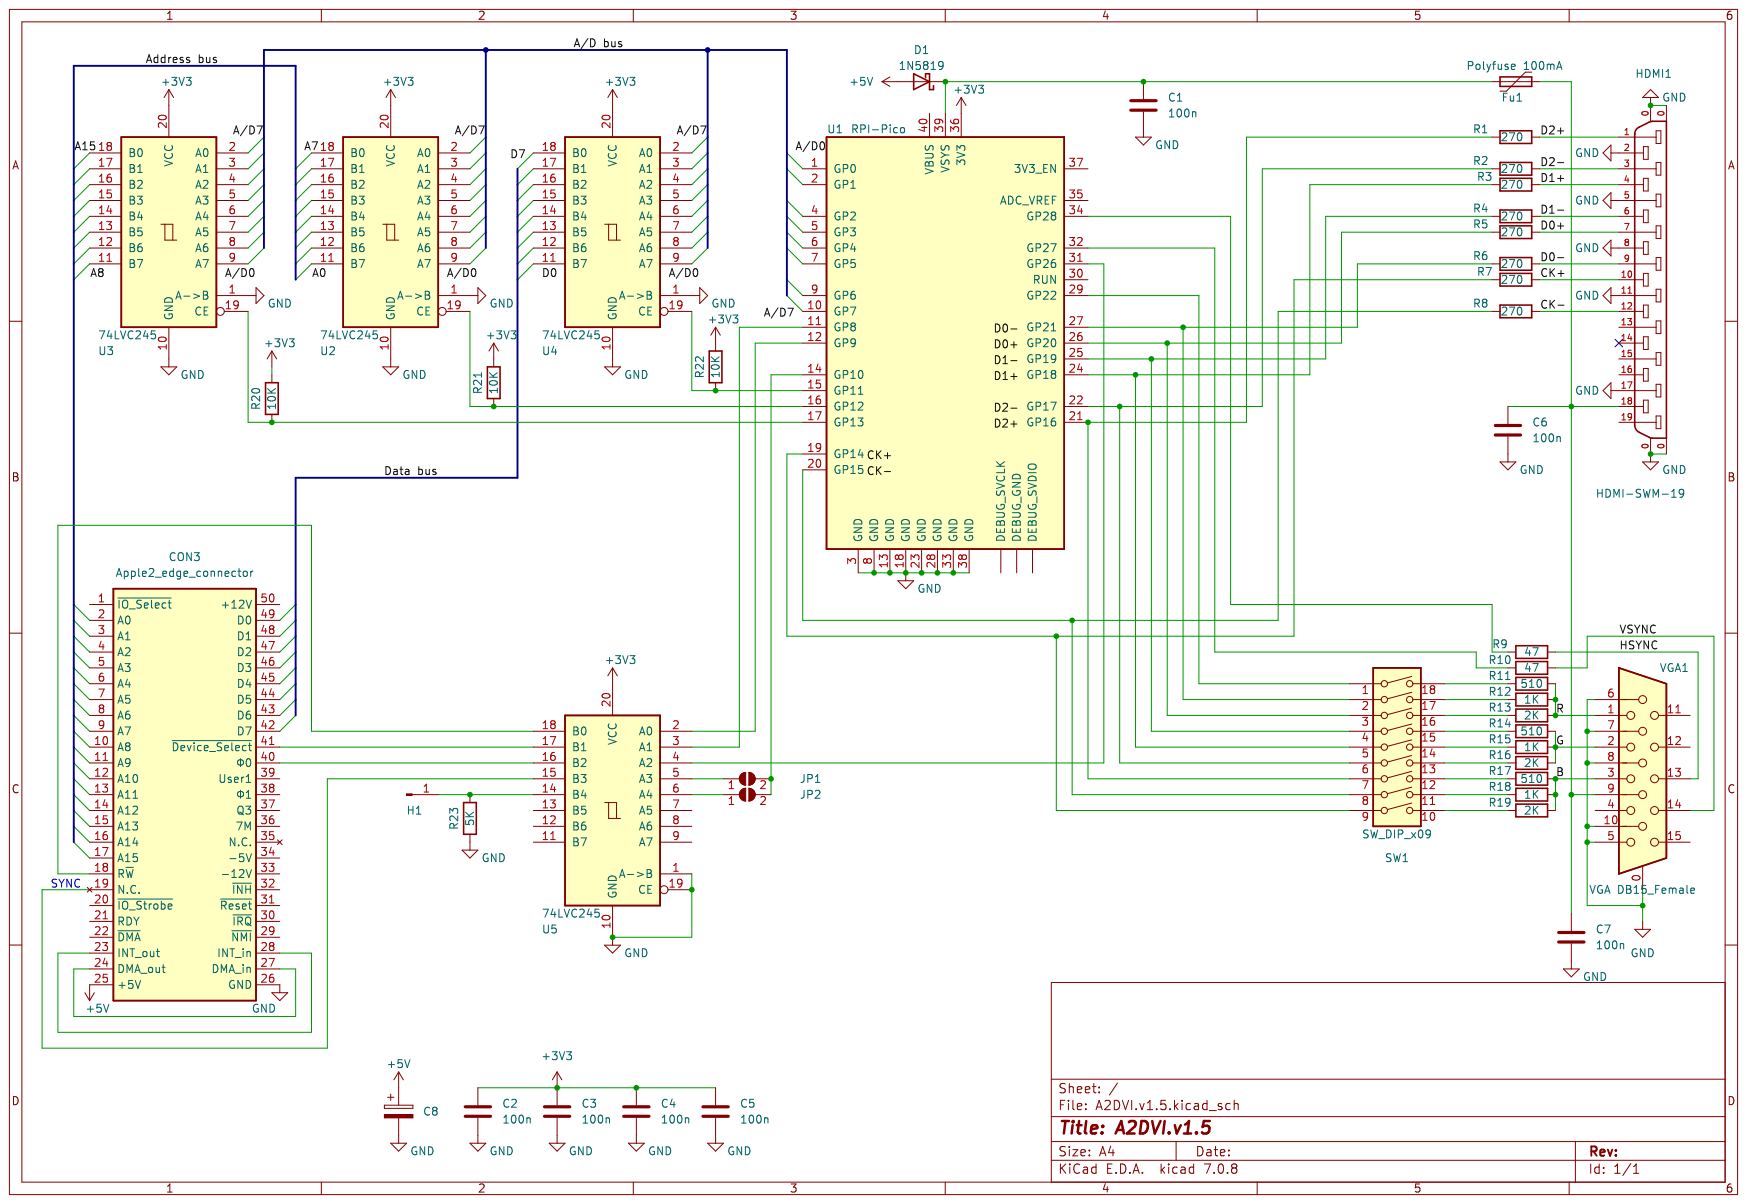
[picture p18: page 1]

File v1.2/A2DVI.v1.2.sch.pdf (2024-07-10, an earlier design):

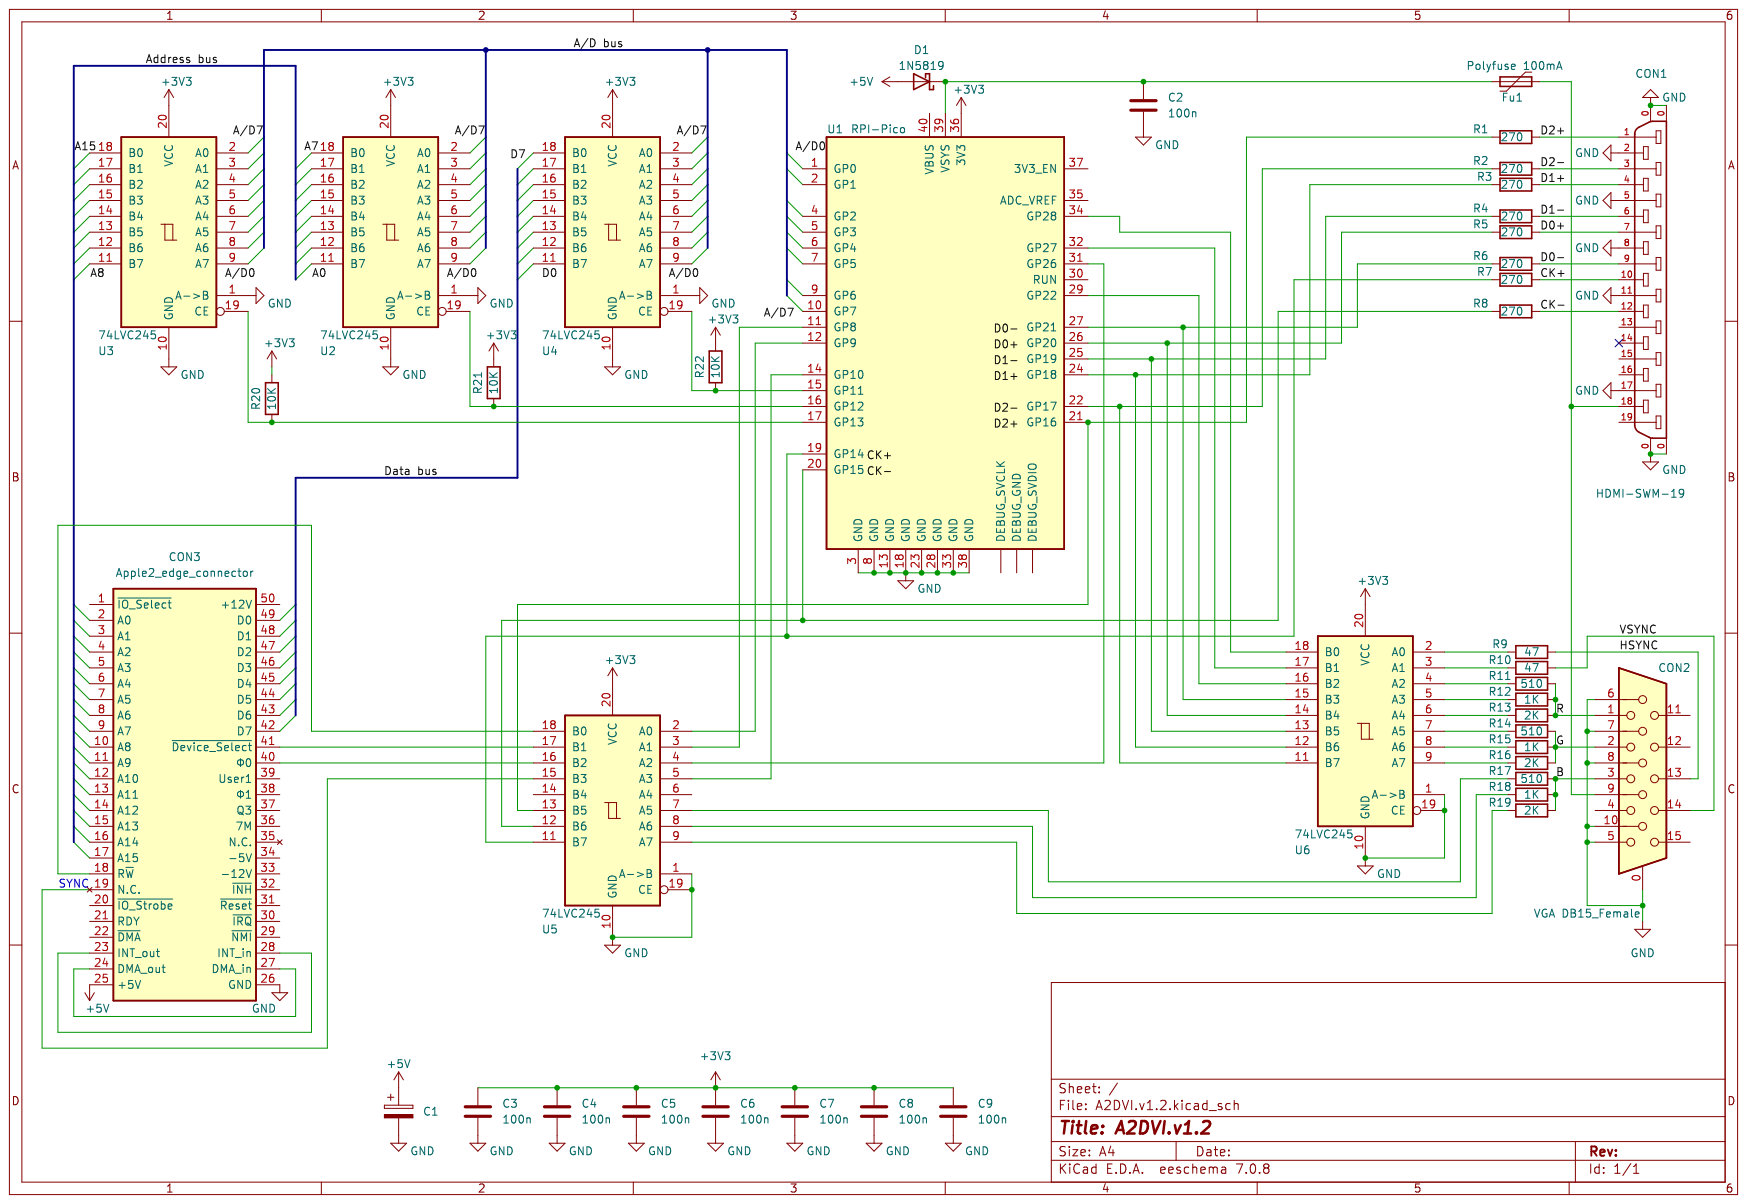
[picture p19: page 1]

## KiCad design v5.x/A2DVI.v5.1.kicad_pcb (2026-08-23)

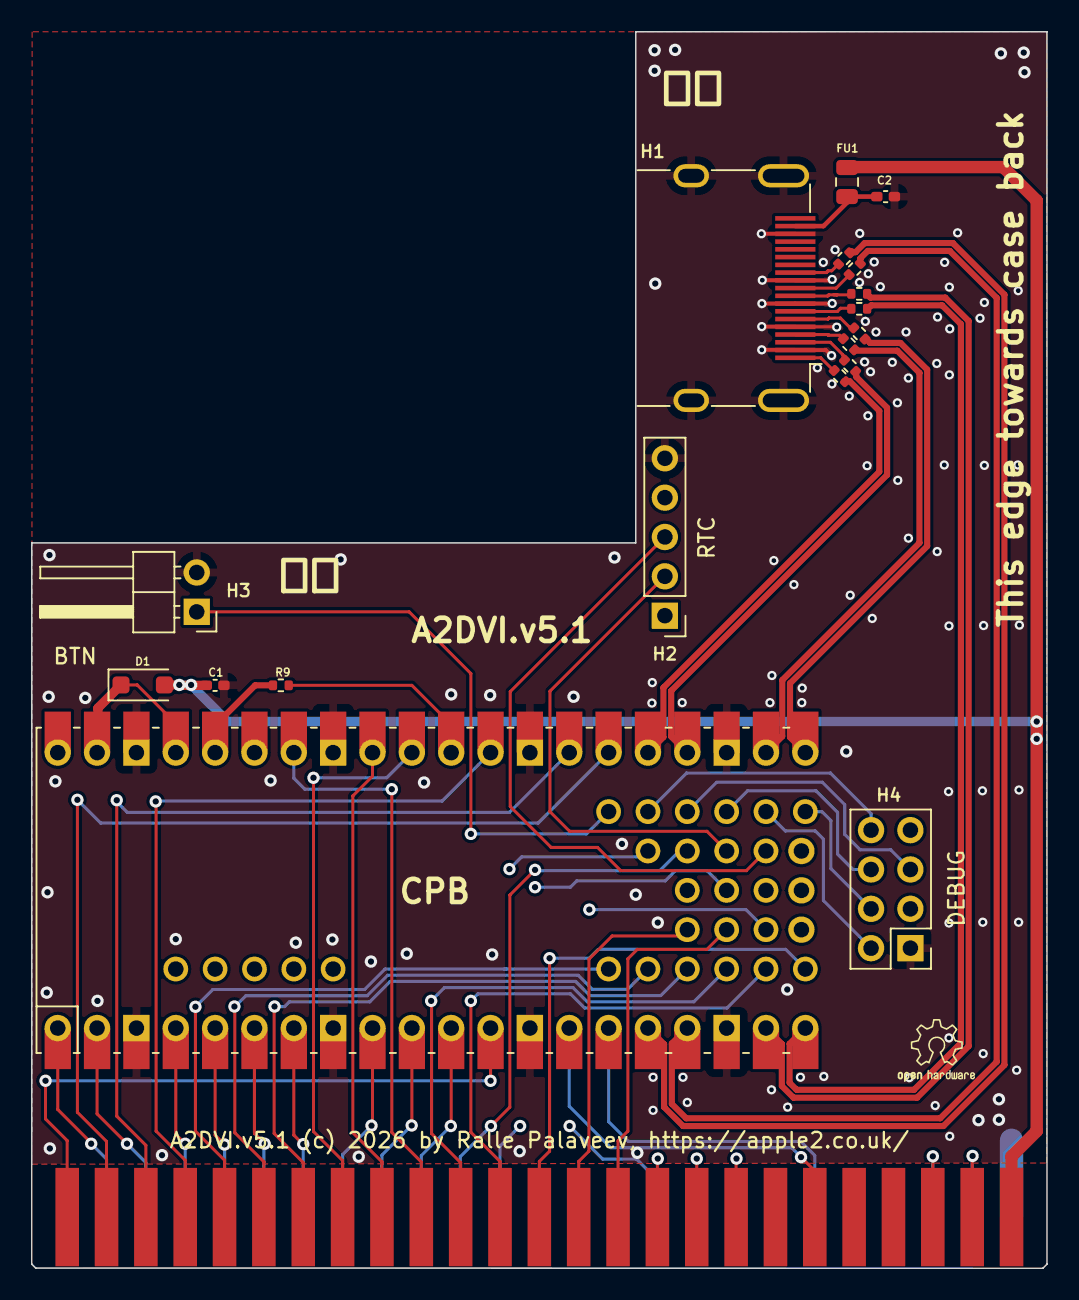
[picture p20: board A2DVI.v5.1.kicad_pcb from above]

Board: 4 copper layers, 65.5 x 79.8 mm, 18 parts (0 on the bottom side), 22 nets.

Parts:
C1, C2: 100n; C_0402_1005Metric_Pad0.74x0.62mm_HandSolder
D1: D_SOD-123F
FU1: 100mA; Fuse_0805_2012Metric
H1: HDMI_A_Molex_208658-1001_Horizontal
H2: PinHeader_1x05_P2.54mm_Vertical
H3: PinHeader_1x02_P2.54mm_Horizontal
H4: PinHeader_2x04_P2.54mm_Vertical
R1, R2, R3, R4, R5, R6, R7, R8: 270; R_0402_1005Metric
R9: 1k; R_0402_1005Metric
U1: CPB; CPB_SMD_TH

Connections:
3.3V: H2.1, H4.7, R9.2, U1.36
5V: C1.2, D1.2, FU1.2
5V_out: C2.2, FU1.1, H1.18
BTN: H3.1, U1.41
CLK_N: R8.1, U1.16
CLK_P: R7.1, U1.17
CS: H4.4, U1.46
D0_N: R6.1, U1.19
D0_P: R5.1, U1.20
D1_N: R4.1, U1.21
D1_P: R3.1, U1.22
D2_N: R2.1, U1.24
D2_P: R1.1, U1.25
GND: C1.1, C2.1, H1.2, H1.5, H1.8, H1.11, H1.17, H1.SH, H2.5, H3.2, H4.1, U1.3, U1.8, U1.13, U1.18, U1.23, U1.28, U1.33, U1.38
I2C_SCL: H2.3, U1.50
I2C_SDA: H2.2, U1.49
LED: H4.8, U1.42
RUN: R9.1, U1.30
UART_RX: H4.6, U1.44
UART_TX: H4.5, U1.43
UART_extra: H4.2, U1.45
VSYS: D1.1, U1.37, U1.39

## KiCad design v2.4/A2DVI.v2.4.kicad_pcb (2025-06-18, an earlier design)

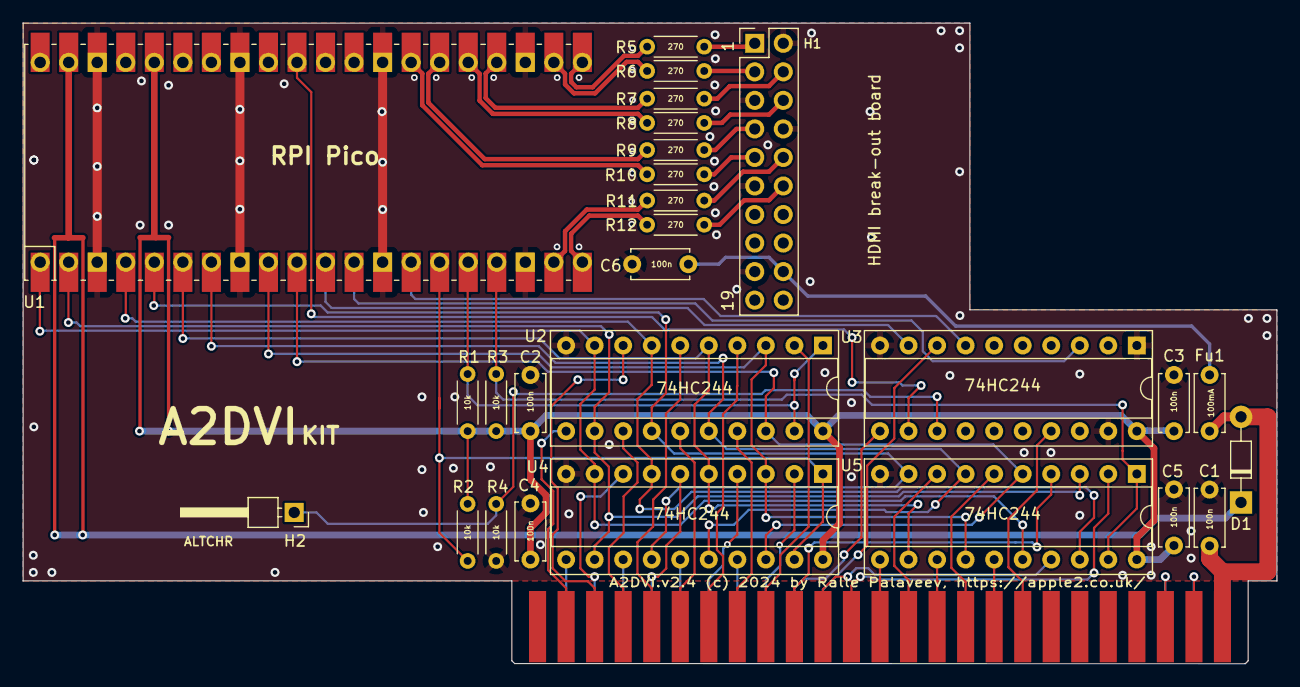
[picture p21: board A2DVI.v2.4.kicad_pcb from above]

Board: 2 copper layers, 111.6 x 57.0 mm, 27 parts (0 on the bottom side), 29 nets.

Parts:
C1, C2, C3, C4, C5, C6: 100n; C_Disc_D5.0mm_W2.5mm_P5.00mm
D1: D_DO-34_SOD68_P7.62mm_Horizontal
Fu1: 100mA; C_Disc_D5.0mm_W2.5mm_P5.00mm
H1: PinHeader_2x10_P2.54mm_Vertical
H2: PinHeader_1x01_P2.54mm_Horizontal
R1, R2, R3, R4: 10k; R_Axial_DIN0204_L3.6mm_D1.6mm_P5.08mm_Horizontal
R5, R6, R7, R8, R9, R10, R11, R12: 270; R_Axial_DIN0204_L3.6mm_D1.6mm_P5.08mm_Horizontal
U1: Pico; RPi_PicoW_SMD_TH
U2, U3, U4, U5: 74HC244; DIP-20_W7.62mm_Socket

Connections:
3.3V: C2.1, C3.1, C4.1, C5.1, R1.2, R2.2, R3.2, U1.36 (3V3), U2.20, U3.20, U4.20, U5.20
5V: C1.2, D1.2, Fu1.1
5Vout: C6.2, Fu1.2, H1.18
AD0: U1.1 (GPIO0), U2.9, U4.9, U5.16
AD1: U1.2 (GPIO1), U2.12, U4.12, U5.3
AD2: U1.4 (GPIO2), U2.7, U4.7, U5.18
AD3: U1.5 (GPIO3), U2.14, U4.14, U5.9
AD4: U1.6 (GPIO4), U2.5, U4.5, U5.12
AD5: U1.7 (GPIO5), U2.16, U4.16, U5.7
AD6: U1.9 (GPIO6), U2.3, U4.3, U5.14
AD7: U1.10 (GPIO7), U2.18, U4.18, U5.5
AltChr: H2.1, R4.2, U3.13
CK_N: H1.12, R12.1, R12.2, U1.20 (GPIO15)
CK_P: H1.10, R11.1, R11.2, U1.19 (GPIO14)
D0_N: H1.9, R10.1, R10.2, U1.27 (GPIO21)
D0_P: H1.7, R9.1, R9.2, U1.26 (GPIO20)
D1_N: H1.6, R8.1, R8.2, U1.25 (GPIO19)
D1_P: H1.4, R7.1, R7.2, U1.24 (GPIO18)
D2_N: H1.3, R6.1, R6.2, U1.22 (GPIO17)
D2_P: H1.1, R5.1, R5.2, U1.21 (GPIO16)
DATAOE: R2.1, U1.15 (GPIO11), U4.1, U4.19
GND: C1.1, C2.2, C3.2, C4.2, C5.2, C6.1, H1.2, H1.5, H1.8, H1.11, H1.17, R4.1, U1.3 (GND), U1.8 (GND), U1.13 (GND), U1.18 (GND), U1.23 (GND), U1.28 (GND), U1.33 (AGND), U1.38 (GND), U2.10, U3.1, U3.10, U3.19, U4.10, U5.10
L-AltChr: U1.14 (GPIO10), U3.7
L-DevSel: U1.11 (GPIO8), U3.9
L-PHI0: U1.31 (GPIO26_ADC0), U3.12
L-RW: U1.12 (GPIO9), U3.3
LSBOE: R1.1, U1.16 (GPIO12), U2.1, U2.19
MSBOE: R3.1, U1.17 (GPIO13), U5.1, U5.19
VSYS: D1.1, U1.39 (VSYS)

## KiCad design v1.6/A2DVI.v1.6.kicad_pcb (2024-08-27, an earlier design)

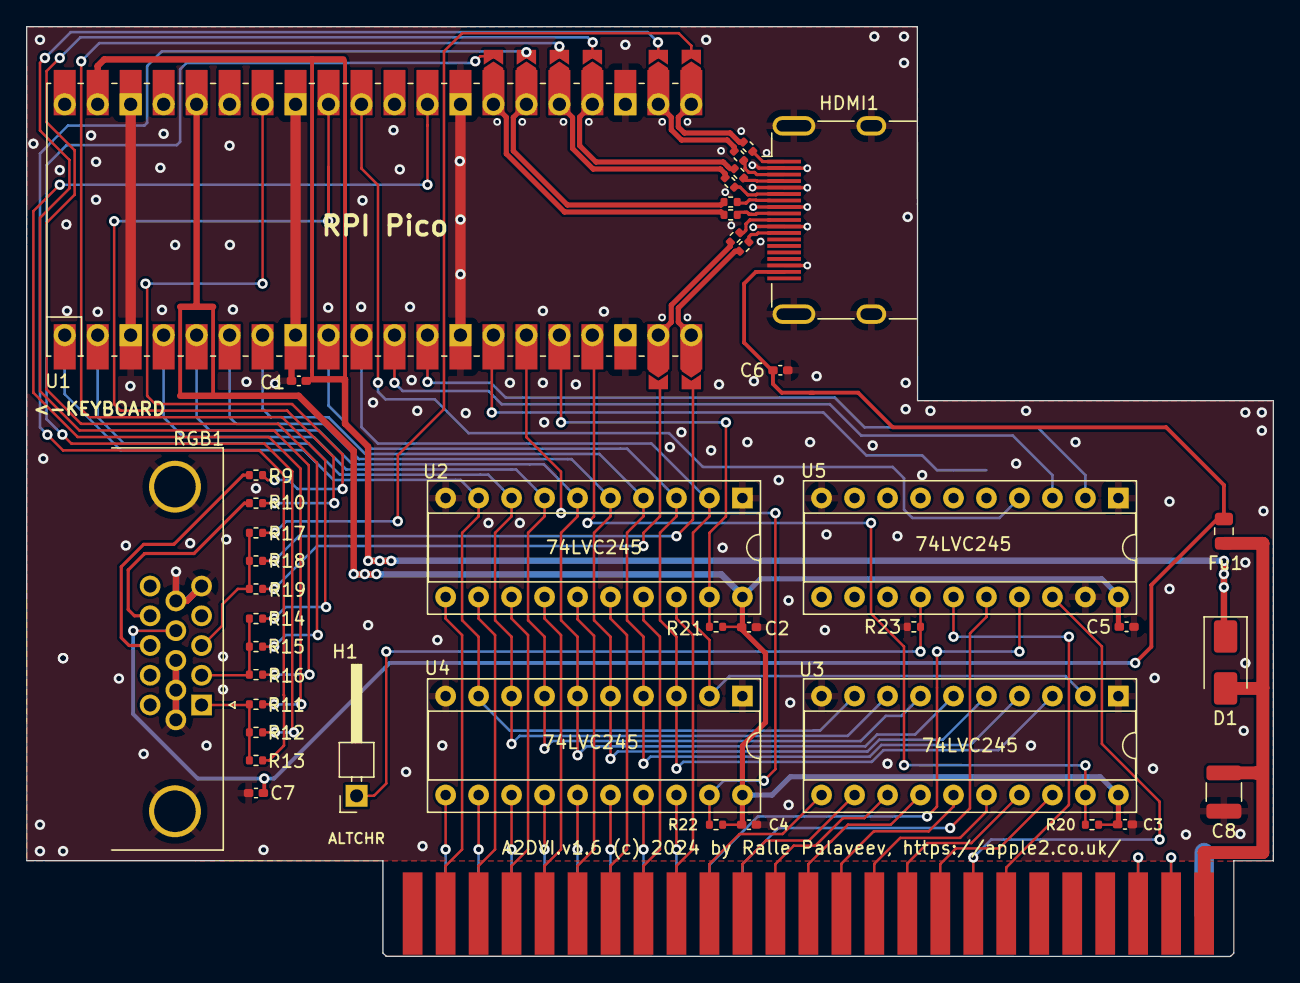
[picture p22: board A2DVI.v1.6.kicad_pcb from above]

Board: 2 copper layers, 96.0 x 71.6 mm, 41 parts (0 on the bottom side), 37 nets.

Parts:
C1, C2, C3, C4, C5, C6, C7: 100n; C_0402_1005Metric_Pad0.74x0.62mm_HandSolder
C8: C_1210_3225Metric
D1: SS16; D_SMA
Fu1: Fuse_0805_2012Metric
H1: PinHeader_1x01_P2.54mm_Horizontal
HDMI1: HDMI_A_Molex_208658-1001_Horizontal
R1, R2, R3, R4, R5, R6, R7, R8: 270; R_0402_1005Metric
R9, R10: 47; R_0402_1005Metric
R11, R14, R17: 510; R_0402_1005Metric
R12, R15, R18: 1k; R_0402_1005Metric
R13, R16, R19: 2k; R_0402_1005Metric
R20, R21, R22: 10k; R_0402_1005Metric
R23: 5k; R_0402_1005Metric
RGB1: DB15_Female_HighDensity_MountingHoles; DSUB-15-HD_Female_Horizontal_P2.29x1.98mm_EdgePinOffset3.03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
U1: Pico; RPi_PicoW_SMD_TH
U2, U3, U4, U5: 74LVC245; DIP-20_W7.62mm_Socket

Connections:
3.3V: C2.1, C3.2, C4.1, C5.2, R20.2, R21.2, R22.2, U1.36 (3V3), U2.20, U3.20, U4.20, U5.20
5V: C8.2, D1.2, Fu1.2
5V_out: C6.2, C7.1, Fu1.1, HDMI1.18, RGB1.9
AD0: U1.1 (GPIO0), U2.9, U3.9, U4.9
AD1: U1.2 (GPIO1), U2.8, U3.8, U4.8
AD2: U1.4 (GPIO2), U2.7, U3.7, U4.7
AD3: U1.5 (GPIO3), U2.6, U3.6, U4.6
AD4: U1.6 (GPIO4), U2.5, U3.5, U4.5
AD5: U1.7 (GPIO5), U2.4, U3.4, U4.4
AD6: U1.9 (GPIO6), U2.3, U3.3, U4.3
AD7: U1.10 (GPIO7), U2.2, U3.2, U4.2
Altchr: H1.1, R23.2, U5.14
B_out: R17.1, R18.1, R19.1, RGB1.3
CK_N: R8.1, U1.20 (GPIO15)
CK_P: R7.1, U1.19 (GPIO14)
D0_N: R6.1, U1.27 (GPIO21)
D0_P: R5.1, U1.26 (GPIO20)
D1_N: R4.1, U1.25 (GPIO19)
D1_P: R3.1, U1.24 (GPIO18)
D2_N: R2.1, U1.22 (GPIO17)
D2_P: R1.1, U1.21 (GPIO16)
D2_otut_P: HDMI1.1, R1.2
DATAOE: R22.1, U1.15 (GPIO11), U4.19
GND: C1.1, C2.2, C3.1, C4.2, C5.1, C6.1, C7.2, C8.1, HDMI1.2, HDMI1.5, HDMI1.8, HDMI1.11, HDMI1.17, HDMI1.SH, R23.1, RGB1.0, RGB1.5, RGB1.6, RGB1.7, RGB1.8, RGB1.10, U1.3 (GND), U1.8 (GND), U1.13 (GND), U1.18 (GND), U1.23 (GND), U1.28 (GND), U1.33 (AGND), U1.38 (GND), U2.1, U2.10, U3.1, U3.10, U4.1, U4.10, U5.1, U5.10, U5.19
G_out: R14.1, R15.1, R16.1, RGB1.2
HSYNC: R9.2, U1.34 (GPIO28_ADC2)
HSYNC_out: R9.1, RGB1.13
L-DevSel: U1.11 (GPIO8), U5.3
L-PHI0: U1.31 (GPIO26_ADC0), U5.4
L-RW: U1.12 (GPIO9), U5.2
LSBOE: R21.1, U1.16 (GPIO12), U2.19
MSBOE: R20.1, U1.17 (GPIO13), U3.19
R0: R11.2, U1.29 (GPIO22)
R_out: R11.1, R12.1, R13.1, RGB1.1
VSYNC: R10.2, U1.32 (GPIO27_ADC1)
VSYNC_out: R10.1, RGB1.14
VSYS: C1.2, D1.1, U1.39 (VSYS)

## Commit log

2026-08-23 Add description for Clintech Pico Board (CPB)
2026-08-23 Add additional PCB images to README
    Added images for A2DVI PCB versions 4.6 and 5.1.

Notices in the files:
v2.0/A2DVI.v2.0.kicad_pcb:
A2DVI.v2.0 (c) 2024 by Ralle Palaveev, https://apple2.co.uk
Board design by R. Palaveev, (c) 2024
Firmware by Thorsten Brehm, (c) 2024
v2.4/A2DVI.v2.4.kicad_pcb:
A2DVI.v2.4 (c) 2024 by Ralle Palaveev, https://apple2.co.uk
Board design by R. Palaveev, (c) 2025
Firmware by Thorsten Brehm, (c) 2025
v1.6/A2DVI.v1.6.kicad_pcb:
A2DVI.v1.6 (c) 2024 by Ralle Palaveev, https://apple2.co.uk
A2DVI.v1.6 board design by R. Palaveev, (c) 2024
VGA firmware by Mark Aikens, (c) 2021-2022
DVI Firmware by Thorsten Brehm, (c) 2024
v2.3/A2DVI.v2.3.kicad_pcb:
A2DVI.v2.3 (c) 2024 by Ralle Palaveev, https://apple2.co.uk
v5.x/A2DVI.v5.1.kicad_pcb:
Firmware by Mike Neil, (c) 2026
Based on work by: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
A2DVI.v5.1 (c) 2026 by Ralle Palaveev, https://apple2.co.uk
